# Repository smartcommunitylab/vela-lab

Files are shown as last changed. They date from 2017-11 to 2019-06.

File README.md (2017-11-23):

Smart City Vela Lab
========================

This repository contains the code for the embedded network devices used in the Smart City Lab located in Vela (Trento, Italy).
The network components are:
- BLE Beacons: Eddystone or CLIMB (https://github.com/smartcommunitylab/sco.climb.driverapp) proprietary beacons
- BLE Scanner: Nordic nRF52 DK (nRF52832 SoC)
- Mesh Node: Texas Instruments cc2650 launchpad
- Mesh Sink: Texas Instruments cc2650 launchpad
- Gateway: Raspberry PI

The BLE Scanner and the Mesh Node are packed into the same case and together they are called Mobile Stack. The communication between the two boards happen through the UART interface. The same apply for the Mesh Sink and the Gateway, in this case the communication take place over an emulated serial port over USB.

The purpose of this network is to collect 'contacts' of BLE Beacons and push them, through the mesh network, to a cloud infrastructure (database).

For this purpose, the BLE Scanner scans for neighboring devices. When requested, the information regarding contacts (for instance the list of IDs with their RSSI) are passed to the Mesh Node, which injects this data into the mesh network. When the data reach the Mesh Sink it forward it to the Gateway that push the data to the cloud.

The deployment is at very early stage, than the code may have bugs and the compilation process may not be straigh forward, nevertheless we try to describe the steps for setting up the environment in the README-BUILDING.md file in this directory.

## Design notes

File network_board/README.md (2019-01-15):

Mesh devices
========================

This folder contains the code specifically developed for the Mesh Node and for the Mesh Sink. Note that external sources/libraries may be required. Every folder contains all the code required to compile a fully working program. 

The folder basic_i2c_init includes the files for setting up i2c communication to communicate with the fuel gauge on the PCB.

The folder basic_sender_test includes the files used for the network/application layer of the nodes and sink.

The folder basic_sink includes files used for the sink, but these are outdated. The current version is in basic_sender_test.

The folder basic_uart_init contains the files used for the UART communication between the node and the Nordic.

The folder integrate_sender_uart contains the code that will be uploaded to the nodes during deployment. When using the buildscript the following files are copied into this folder:
-basic_uart_init/vela_uart.c 
-basic_uart_init/vela_uart.h 
-basic_sender_test/vela_sender.c 
-basic_sender_test/vela_sender.h 
-basic_sender_test/sink_receiver.c
-basic_sender_test/sink_receiver.h

Warning: Editing these files should be done in their original folder. If you change these files in integrate_sender_uart all progress will be lost when the build script is called. 

The following problems have been encountered in the past:
-RPL_DEFAULT_ROUTE_INFINITE_LIFETIME: setting this to 0 can cause the nodes to lose connection to the sink frequently.
-NETSTACK_CONF_RDC_CHANNEL_CHECK_RATE: setting this to 1 can cause the nodes to reboot periodically (cause unknown).
-Seemingly random reboots that were fixed by changing all variables to static when possible.

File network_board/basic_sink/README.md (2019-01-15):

Mesh Sink: basic
========================

Warning: this code may be outdated compared to the sink from basic_sender_test and integrate_sender_uart.
This code contains an example code of the program running on the Mesh Sink (TI cc2650). 
This example code prints any received messages.

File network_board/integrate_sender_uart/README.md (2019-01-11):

Integrate sender uart
========================

This code merges the two projects: basic_uart_init and basic_sender_test to make the firmware complete and able to use both the uart and the wireless mesh network.
The whole project contains just two c files: vela_node.c and vela_sink.c. The other needed files are copied from:
-basic_uart_init/vela_uart.c 
-basic_uart_init/vela_uart.h 
-basic_sender_test/vela_sender.c 
-basic_sender_test/vela_sender.h 
-basic_sender_test/sink_receiver.c
-basic_sender_test/sink_receiver.h
To do so, just run the copyForBuild.sh script before building.

Warning: Editing these files should be done in their original folder. If you change these files in integrate_sender_uart all progress will be lost when the build script is called.

Within this code are 4 processes.

-Vela_sender_process
This process is responsible for the sending of data through RPL and fragmenting it. The data includes BLE reports, pong messages, and battery data.

-Trickle_protocol_process
This process sends and handles incoming Trickle messages. Trickle messages are used to configure all the nodes in the network.

-Keep_alive_process
This process sends a periodic keep alive message. The interval of these keep alive messages can be changed by the gateway using Trickle messages.

-cc2650_uart_process
This process handles all UART communication between the CC2650 and the Nordic.

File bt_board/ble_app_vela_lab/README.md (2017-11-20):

BLE Scanner:ble app vela lab
========================

This code contains the program running on the Bluetooth Scanner device. Its behaviour is strictly correlated with the Mesh Node which is connected to the BLE Scanner through the UART interface.
At the boot the device is initialized but without any command by the Mesh Node the BLE Scanned doesn't do anything else, is up the the Mesh Node to start the Bluetooth and request the periodic Bluetooth contacts report.
This code is the actual code that is supposed to run on the BLE Scanner of the Vela Lab.
This code requires nRF5 SDK (v14.0.0) installed and linked (see the README-BUILDING.md at the repository root).

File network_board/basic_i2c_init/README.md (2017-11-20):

Mesh Node: test uart
========================

This code contains an example code of the program running on the Mesh Node (TI cc2650). 
This example do not use any kind of wireless interface.
The aim of this code is to show how to use the UART for communicating with the BLE Scanner. To this purpose the TI send forces an hard reset on the BLE Scanner, waits for the uart_ready packet, and then it start sending initialization packets (set BLE scan parameters, set BLE scan ON, request periodic report).
At this point the reports are automatically sent by the BLE Scanner to the Mesh Node.
As the full report is received it calls report_ready(uint8_t *p_buff, uint16_t size) where 'p_buff' points to the report and 'size' is its size. Note that the data stored in the buffer does not include the TYPE field, it is the raw list of contacts. 
For now the structure of the contacts isn't really fixed, to know the exact format look into: /bt_board/ble_app_vela_lab/main.c : add_node_to_report_payload(...)

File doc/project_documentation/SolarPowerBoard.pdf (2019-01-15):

# Solar power board

## Contents

## General description

The design of the power-board used to power nodes with solar energy is explained in this document. The design exists out of 5 stages: solar power input, USB power input, energy storage, a fuel gauge, and a DC/DC regulator to provide suitable power to the node. For clarification, a simplified version of the board is provided below.

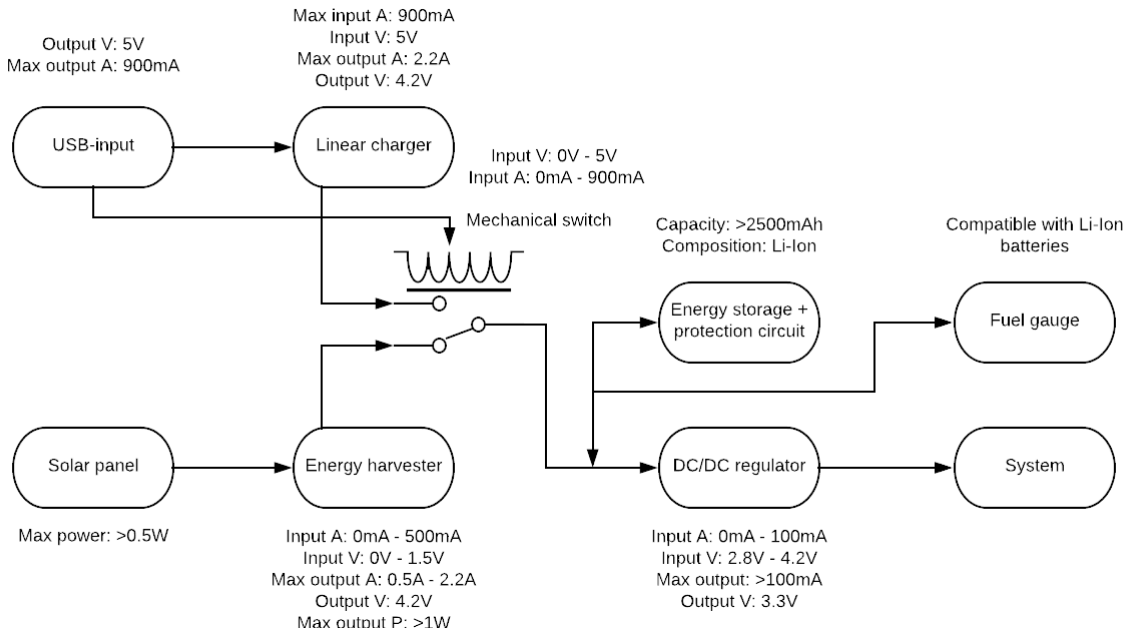
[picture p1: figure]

The board receives power from USB-input or from the solar panel. Once the node is deployed outside USB input won’t be utilized. The USB-input power is used when the node is being charged indoors. Input power goes through an IC (energy harvester or linear charger) to optimize/regulate the power for the rest of the circuit. The power will be used to power the system and to charge the battery. The battery will be used to power the system when there is no other power source available. The fuel gauge measures the state of the battery and can predict how long the battery can last. Before any source is used to power the system (including the battery), it passes the DC/DC regulator. This transforms the input voltage to an output voltage that is suitable for the system that will be powered.

The board has 2 charging options, with a USB connection or using a solar panel. USB charging will happen when the node is plugged into a laptop or pc. This won’t happen outside, so the solar panel will not be useful in this situation. When there is a high voltage on the USB-input, the relay will close the connection between the linear charger and the energy storage and open the connection between the solar panel and the energy storage. When the node is plugged out of the laptop or pc the connection between the energy storage and the linear charger opens again, and the connection between the energy storage and the solar power closes again.

The linear charger connected to the USB-input optimizes the charging of the battery. An FTDI chip is connected to the USB-input that functions as a USB to UART interface. The energy harvester connected to the solar panel maximizes the extracted power from the solar panel and regulates the output voltage. The energy storage has a protection circuit that disconnects the battery for charging or discharging in case of a detected fault.

The selected components are:

-USB-input FTDI chip: FT230XQ-R

-Linear charger: MCP73831T-2ACI/OT

- Solar panel: 1W Solar Panel 80X100 or Sparkfun 2W solar panel

-Energy harvester: SPV1040

-Protection circuit: BQ29700

-Energy storage: JA-18650 Li-Ion battery pack (S1P3)

-Fuel gauge: MAX17260DSET

-DC/DC regulator: TPS63031DSK

## Solar panel

Power consumption
The decision of what solar panel to use depends on the consumed power. In order to choose a suitable solar panel, the total power consumption and the efficiency must be calculated. Based on these 2 factors the size of the solar panel can be chosen.

Psolar panel * ηsystem > Pconsumed

Harvested energy
The amount of energy that will be harvested by a solar panel is dependent on 3 factors: solar irradiance, panel size, and efficiency.
This site shows how much solar irradiance lands on a city http://solarelectricityhandbook.com/solar-irradiance.html. (http://solarelectricityhandbook.com/solar-irradiance.html)
This can be used as an estimation of the available energy, keep in mind however that the mountains can obstruct sun which means less energy will be available than stated. Multiply the solar irradiance by the panel size (m2) and the panels efficiency and you have a very rough estimation of the amount of energy that will be harvested. The actual amount will be lower.

Output current
In order to ensure maximum efficiency, make sure the output current of the solar panel is not greater than the maximum charging current of the battery plus the power consumption from the boards. If that is not the case, not all the harvested energy can be used.

## Energy harvester

Function
The energy harvester’s (SPV1040) task is to extract power from the solar panel. This component is needed because the solar panel’s output is unstable. Of course, the output power depends on the amount of sun on the panel, and since this varies a lot throughout the day the output will change a lot. The energy harvester takes the irregular input from the solar panel and stabilizes it, so the output of the energy harvester can be used to charge a battery. Another important feature of this component is MPPT. Not every energy harvester has this feature, but it is an important one. MPPT ensures that the highest possible amount of power is harvested from the solar panel, by dynamically finding the voltage point at which the power harvested is the greatest. The input voltage range of the SPV1040 (0 – 5.5V) may seem too low for the solar panel’s output voltages (up to 6V), but after consulting with someone who has more experience in this field, it has been decided this should not be a problem.

Maximum ratings:
Input voltage: 5.5V
Input current: 1.8A
Output voltage: 5.2V

Configuring the output
Below is the schematic of the SPV1040 including passive components:

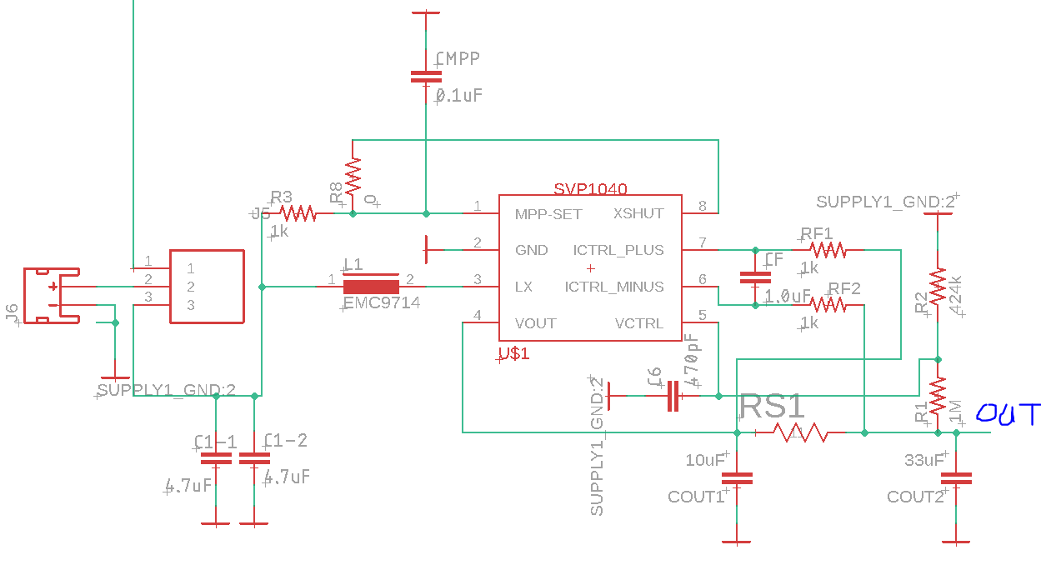
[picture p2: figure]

Figure 1 SPV1040 schematic. (jumper pin 1 is an optional bypass)

The output voltage can be set using R1 and R2 using the following formula: R1
R2

=

Voutmax
1.25
Where R1 is 1Mohm.

The maximum output current can be limited with RS1 using the following formula:

RS1 =

50mV
Ioutmax

For more details refer to application note ST AN3319.

Rejected alternatives
Several different energy harvesters are available, but the SPV1040 was the best fit. Most energy harvesters were deemed not suitable based on voltage input range or maximum output/input current.
The LTC4010 was deemed not suitable because of the high quiescent current.
The BQ24210 seemed like a good option as well, but it did not have MPPT.
The SVP1050 had a maximum charging current of 70mA, which would mean a lot of energy would be wasted.
BQ25504 had an input voltage range that only allowed a maximum of 3V input, which was way too low.

## FT230XQ-R

Function
This chip is used to handle the communication that happens over the USB connection when the board is plugged into a laptop or something similar. It converts the USB signals to UART so the signals can be understood by the boards. This chip is also used to open a switch once the USB input enters sleep mode, so the charging will be terminated when there is barely any current entering the circuit from the USB connection.

## MCP738312

Function
The MCP is a linear charger used to charge the battery with the power coming in from the USB port.

Output current
The output current is set with the resistor RProg at the PROG pin. The current value of 2k ohm sets the output current at the maximum current possible, 500mA.

## Protection circuit

Function
This circuit has its own battery protection circuit to prevent several faults, such as overcharging, over discharging, overcurrent charging, overcurrent discharging. This protection circuit is suitable with any 3.7V Li-Ion battery. The protection circuit has 2 MOSFET’s connected between the negative battery terminal and the ground. As soon as an error is detected one MOSFET will be set open, blocking either charging or discharging of the battery depending on the error. This way the battery can still be discharged when the charging is terminated, and the battery can still be charged when it’s discharged all the way. This would not be possible using only one MOSFET and simply disconnecting the battery whenever a fault is detected. The protection IC uses voltage sensing and current sensing to detect faults.

Battery type
This protection circuit only works with Li-Ion battery packs that doesn’t have any cells in series.

Overcurrent charging and overcurrent discharging
In the current circuit overcurrent charging and overcurrent discharging are not correctly configured, they are too high. Since the battery that is currently used has a fast charging rating of 1C (2.2A), limiting the charging current is not needed. The SPV1040 regulates the output current and will shut off as soon as the input current rises above 1.8A. Also, research shows overcurrent charging is not dangerous (Tazdin Amietszajew, 2018). The discharge rate of the battery is rated at 0.5C (1.1A). But the absolute maximum rating of the DC/DC converter is 1.1A (which will practically be even less), so there is also no risk of discharging the battery with a current that is too high. If this circuit is changed however, the overcurrent values might have to be configured correctly.

Rejected alternative
The BQ2980 was also considered as protection circuit, however the standard protection values of the BQ2980 weren’t as good as the BQ2870’s values.

## Energy storage

Constraints
The energy storage can be varied without any changes in the circuit, if the following characteristics are the same:
- Battery chemistry: Li-Ion
- Charging voltage: 4.2V
- Battery voltage when fully charged: 4.2V
- Battery voltage when fully discharged: 2.8V

These values are fixed by the protection circuit, so if energy storage with other characteristics are required either select another version of the BQ270x or choose another protection IC.

The maximum charging and discharging current depend on the SPV1040, the protection circuit, and the DC/DC regulator. Refer to the sections of these 2 components to find these currents.

## Fuel gauge

Function
The fuel gauge measures the State of Charge (SoC) of the battery. It implements the ModelGauge m5 algorithm to measure the SoC using coulomb counting, voltage sensing, and an internal temperature sensor. What makes this part very suitable for this project are the low operating current (5uA) and the option to use high-side sensing. Most fuel gauges use low side sensing, but this is not possible for our application. The protection circuit already uses low side current sensing, and having 2 current sense resistors on the same net will cause inaccurate measurements. The fuel gauge contains a lot of data concerning the battery’s state. This data can all be accessed by connected microcontrollers using I²C. The fuel gauge also contains an alert pin to alarm a connected microcontroller in case of a problem (1% SoC left, for example). Important: when connecting the fuel gauge’s sense resistor it is important to do so with a kelvin connection for good accuracy.

Battery type
Li-Ion and LiFePO4 batteries can be used with this fuel gauge. Battery packs with cells that are connected in series will not work with this fuel gauge.

Rejected alternatives
The following fuel gauges were compared to each other: FFG1040UC003X, MAX17043, GG25L, STC3115, MAX1720. The STC3115 was found to be the most efficient. When the protection circuit came into the circuit none of these were suitable anymore, because none of these circuits can use high-side sensing. Also, the energy consumption of all these components is higher than that of the MAX17260.

## DC/DC regulator

Function
The DC/DC regulator transforms its input to a suitable power for the 2 boards. It’s a buck/boost converter, meaning it can output a voltage that is lower or higher than its input voltage. It is optimized for low power application and has a high efficiency (~90%). The output voltage is fixed at 3.3V which is exactly what the boards need.

Maximum ratings:
Input voltage: 1.8V – 5.5V
Output voltage: Fixed at 3.3V
Average current limit: 1A

Rejected alternatives
The previously selected DC/DC regulator TPS62737 was only a buck converter, meaning it could only step-down voltages. This causes problems when the input voltage of the regulator drops below 3.3V. This will happen when the solar panel doesn’t have much sunlight available, or when the battery is discharged a lot. Also, the efficiency of this regulator is not great at the low currents with which the boards have to be supplied.

## Optional connections

There are a few jumpers and DNM resistors throughout the schematic. Their use is explained below:

Jumper at solar panel connection

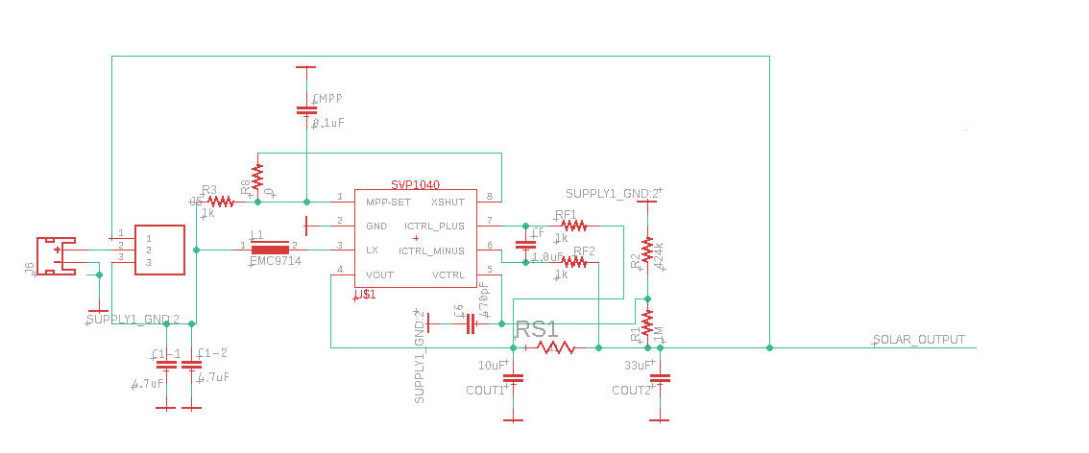
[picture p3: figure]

The jumper at the solar panel connection can be used to bypass the energy harvester. This can be done in case energy harvester is not working, but the solar panel still needs to be tested.

R24

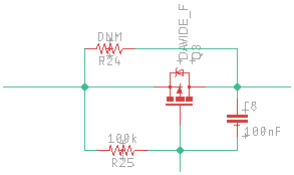
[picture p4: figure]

R24 can be mounted to bypass the switch used to cut off the charging power when the USB enters sleep mode.

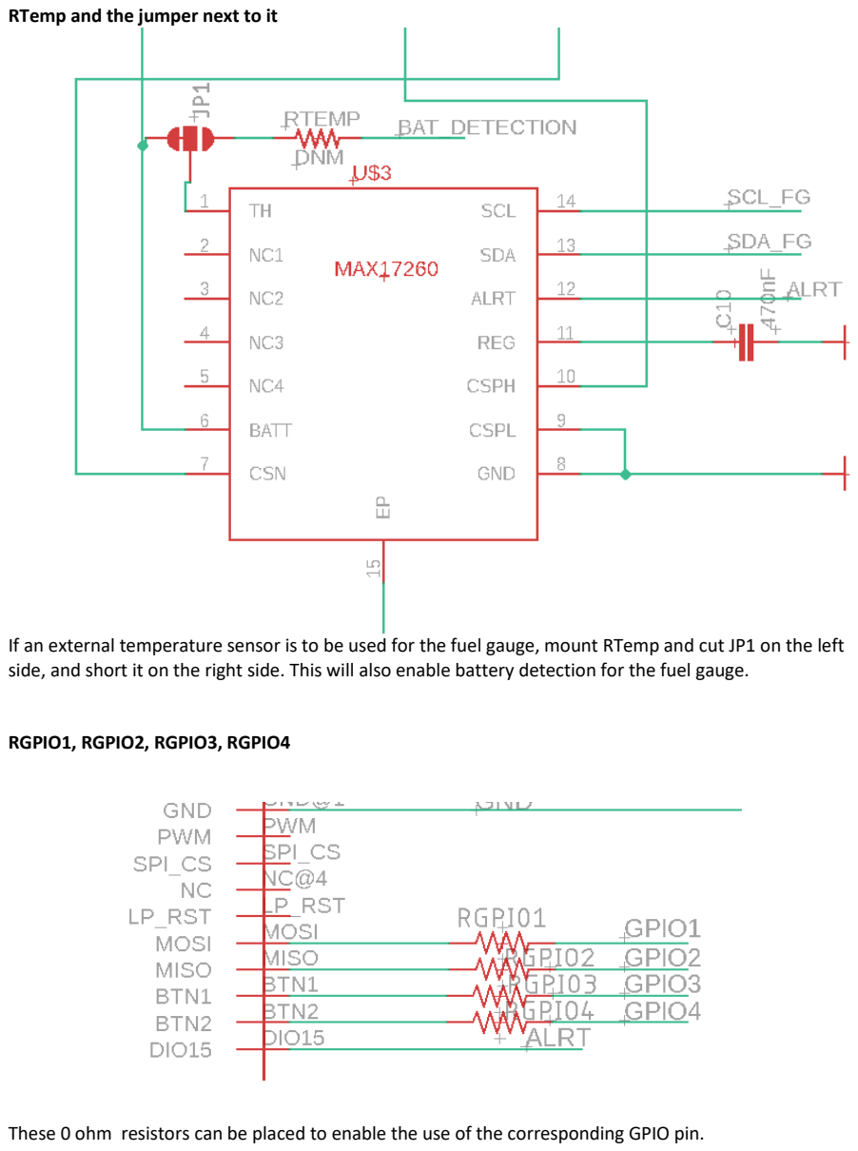
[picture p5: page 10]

RTemp and the jumper next to it

If an external temperature sensor is to be used for the fuel gauge, mount RTemp and cut JP1 on the left side, and short it on the right side. This will also enable battery detection for the fuel gauge.

RGPIO1, RGPIO2, RGPIO3, RGPIO4

These 0 ohm resistors can be placed to enable the use of the corresponding GPIO pin.

SDA jumper

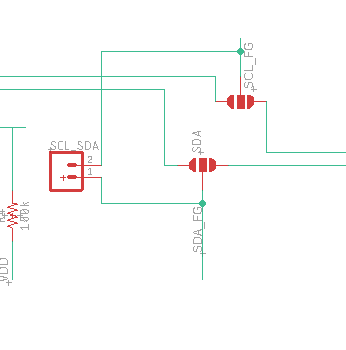
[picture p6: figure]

The SDA jumper should be shorted at least one side to allow the board at the shorted side to communicate with the fuel gauge. If both sides of the jumper are open the fuel gauge is useless.

## Bibliografia

Tazdin Amietszajew, E. M. (2018). Understanding the limits of rapid charging using instrumented commercial 18650 high-energy Li-Ion cells. Coventry: Elsevier.

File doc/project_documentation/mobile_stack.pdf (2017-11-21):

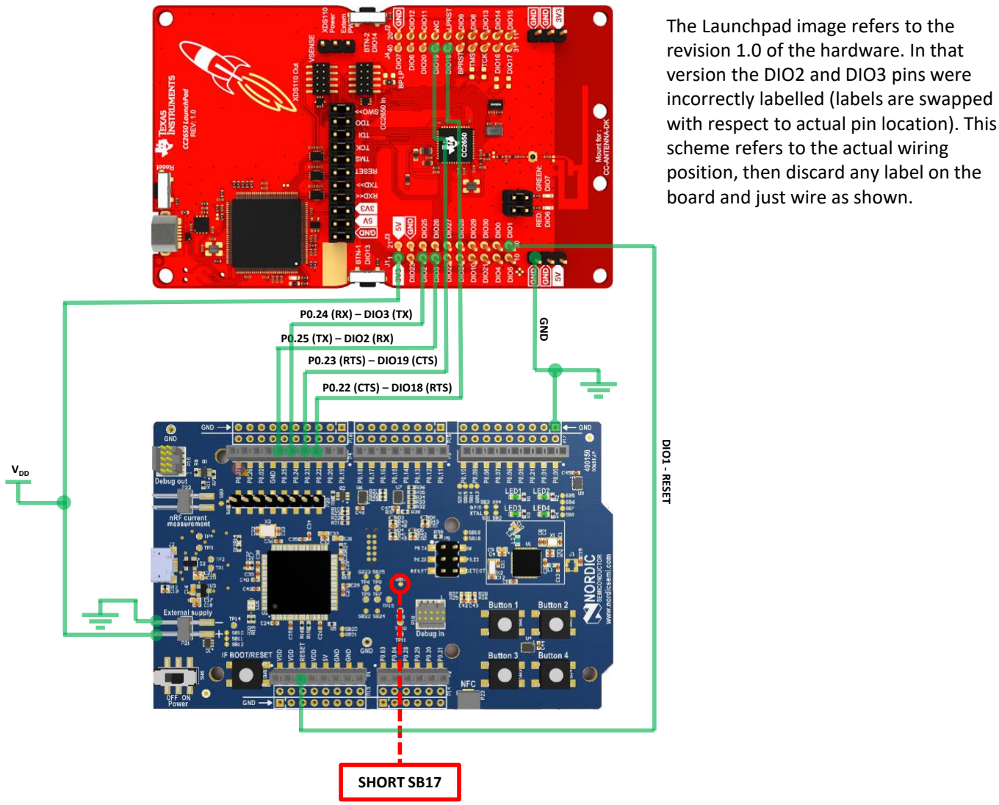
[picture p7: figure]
SHORT SB17; DIO1 - RESET; P0.22 (CTS) – DIO18 (RTS); P0.23 (RTS) – DIO19 (CTS); P0.25 (TX) – DIO2 (RX); P0.24 (RX) – DIO3 (TX); GND; VDD; The Launchpad image refers to the revision 1.0 of the hardware. In that version the DIO2 and DIO3 pins were incorrectly labelled (labels are swapped; scheme refers to the actual wiring position, then discard any label on the board and just wire as shown.

with respect to actual pin location). This

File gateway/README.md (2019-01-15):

Gateway
========================

The Gateway is implemented in python 3 on a Raspberry Pi 3 running Raspiban (ver. June 2017, Kernal 4.9).

Its main functions are:
- read incoming data from the Mesh Sink via serial port (virtual serial port on USB, /dev/ttyACM0)
- defragment (optionally) and decode data from the sink and recode it to the desired internal structures and into a json object
- send the data to the smartcommunity back-end server and log the data
- use the Mesh Sink to send configuration messages into the mesh network based on user input
- log events and data for debugging and testing purposes

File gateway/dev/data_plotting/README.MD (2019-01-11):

This folder contains 3 scripts which are usefull for debugging or analyzing the log files of the gateway.

The first file, applog_plotting.py plots all the battery data and dropped packets based on the log file app.log. 
This file is generated by the script main.py which will run on the gateway during deployment. 
At the moment this script can only plot graphs based on the data of one node. 
Lines 14 and 22 decide from what node's data the graphs should be plotted.

contact_plotter.py plots the RSSI of Bluetooth beacons detections measured by the nodes. 
The data is gathered from the file contact.log which is also generated by the main.py script.
By default this script only works when there is data of 4 different nodes in contact.log, but this can easily be adjusted by:
-Changing the subplotvalues in lines 105 and 108
-Commenting or adding lines to lines 50-53

node_data_logging.py is a script that reads the serial data from a device and logs it to a file with a timestamp.
The file is called [timestamp]-data.log and a new one is generated every time the script is ran.

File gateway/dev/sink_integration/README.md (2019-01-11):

The script main.py is the script that will run on the gateway during deployment.

This script has the following functions:
-Receiving packets from the sink through a serial port and interpreting and (optionally) defragmenting the messages.
-Control the nodes in the network based on user input.
-Log all events for debugging purposes
-Log all received contacts from the nodes.
-Log all the received and sent packets (raw).

Bugs:
-The packet delivery stats that are monitored throughout the script and displayed when the script is closed are wrong. The latest packet of a node is not correctly saved in the function check_for_packetdrop().

To be added:
-Uploading all contacts to a server.

Defragmentation
When the first part of a fragment is received it is kept as a "sequence". A sequence is a list that will contain all the fragments that belong to eachother. When the last fragment of a sequence is received the data of all the fragments gets logged and then the sequence gets deleted so that a new one can be started. Sequences are based on the ID of the sender of the fragment. A sequence is ended when a fragment with the packet type network_last_sequence is received.

User input
The user input is a number that gets entered into the terminal.
The following options are available:
-Request ping
-Enable bluetooth
-Disable bluetooth
-Enable Bluetooth with default settings
-Enable Bluetooth with custom parameters
-Enable the sending of battery info
-Disable the sending of battery info
-Reset all Nordics
-Set keep alive interval in seconds (9 - 254 seconds)

Logfiles
[timestamp]-data.log contains all the logged raw packets.
[timestamp]-contact.log contains all the logged contacts.
[timestamp]-app.log contains all the logged events.

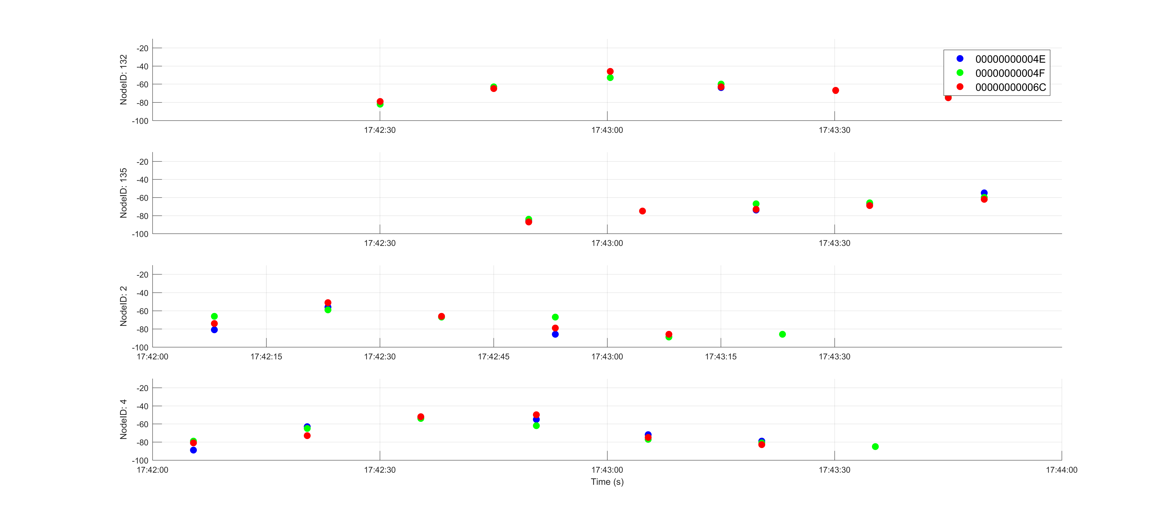
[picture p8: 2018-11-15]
back_end/matlab/45_node.png

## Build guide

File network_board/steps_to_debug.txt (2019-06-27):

24/01/2019 
The nodes still reboot. Once or twice every day when the BT is used
It doesn't look to be directly caused by the uart since the reboots not always happen at the same time. Some times they are very close to the uart communication, some other times are 5 seconds before, sometimes just after a transaction (however I never seen a reboot DURING a uart communication)
Today I'm running a test without the bluetooth (the board is there and the uart is initialized, but the bt scanning isn't enabled). If a reboot will happen it confirms that the cause is not the uart. -> I had one reboot during a weekend even with no uart communication
I have some suspects that the problem is due to some low level race condition
Today I enabled some logs at low level in contiki (contikimac.c, ctimer.c, rtimer.c, ieee-mode.c, rf-core.c, contikimac.c, contikimac_framer.c, nullrdc.c). I try with low level debug and with uart.

30/01/2019
from 24/01 I tried changing the channel check rate, enabling logging at mac layer. Reboots are still there (typically 1 every day, sometimes up to 4) and they happen anywhere (during uart communication, far from uart communication, inbetween uart communications). With the BT DISABLED there are less, but some are still there. Today I run a test with: mac logging enabled, BT off, battery report every 15s, keep alive every 12s, NETSTACK_CONF_RDC_CHANNEL_CHECK_RATE 8

06/03/2019
I tried using 868MHz boards (cc1350) and this one uses by default the PROP_MODE in place of IEEE_MODE that is used in the cc2650. These boards remained outdoor for a couple of weeks. Two of them shown problems: NODEID=5 was not working at all (the red LED was ON and the BT board was in IDLE state), I had to reset it to make it working again. NODEID=3 responded to network commands, however the BT board did not work, even after BT reset command (even ping did not work, the nordic does not respond to ping with pong). After hard reset of the whole node the BT started working again.
Today I run a test with 868MHz radio and PROP_MODE and I remove nodeID=1 since it is the same of the sink...

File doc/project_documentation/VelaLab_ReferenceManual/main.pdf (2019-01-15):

# VelaLab reference Manual

### January 15, 2019

## 1 System Architecture

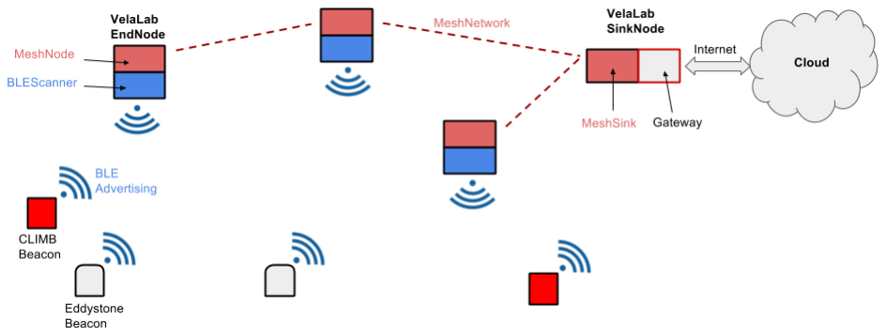
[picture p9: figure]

Figure 1:

### 1.1 Namings and definitions

BLE Beacon
Any beacon device that can be detected from the system. Now it can be of two types: CLIMB Beacon and Eddystone Beacon.

VelaLab EndNode
One of the nodes forming the BLE+mesh network. It is formed by a BLE Scanner and a Mesh Node, which communicate via a serial connection (UART).

1

BLE Scanner
BLE part of an EndNode, based on the Nordinc nRFxx and implemented on the nRFxxx development board.

Mesh Node
Mesh/Contiki part of an EndNode, based on the TI CCxxxxx and implemented on the Lauchpad xxx dev board.

VelaLab SinkNode
The sink/gateway node of the network. It combines the Mesh Sink and the Gateway, which are connected using the serial to USB feature on the Mesh Sink. It does not have the BLE Scanner (only mesh and gateway)

Mesh Sink
The sink node for the mesh/contiki network. Its hardware is equivalent to a Mesh Node, but it has a different firmware.

Gateway
The gateway between the network and the internet/cloud. It is implemented using a Raspberry PI 3 (RPI). The Mesh Sink is connected through a USB port and it connects to the internet through Ethernet or WiFi.

Contact Data Structure
Contact Data is the data structure containing the information about the contact of one BLE Beacon. A Report is an array of Contact Data containing all the data received during the last epoch. All the reported parameters refer to the last epoch.
Field | Type | Size (Byte)
NodeID | uint | 6
lastRSSI | int | 1
maxRSSI | int | 1
pktCounter | u8 | 1

Back-End Data Structure (as in CLIMB)
Data structure containing the information to be sent from the gateway to the server, encoded as a json object. Each call send an array of such objects.

2

Field | Type
wsnNodeId | string
eventType | int
timestamp | int
payload | object

Payload may contain:

Field | Type
passengerId | string
latitude | float
longitude | float
accuracy | float

## 2 Beacons

Types:

- CLIMB (custom)
- Eddystone

## 3 VelaLab End-Node

Components:

- BLE Scanner
- Mesh Node

### 3.1 Hardware interconnection

fig...
The Launchpad image refers to the revision 1.0 of the hardware. In that version the DIO2 and DIO3 pins were incorrectly labelled (labels are swapped with respect to actual pin location). This scheme refers to the actual wiring position, then discard any label on the board and just wire as shown.

3

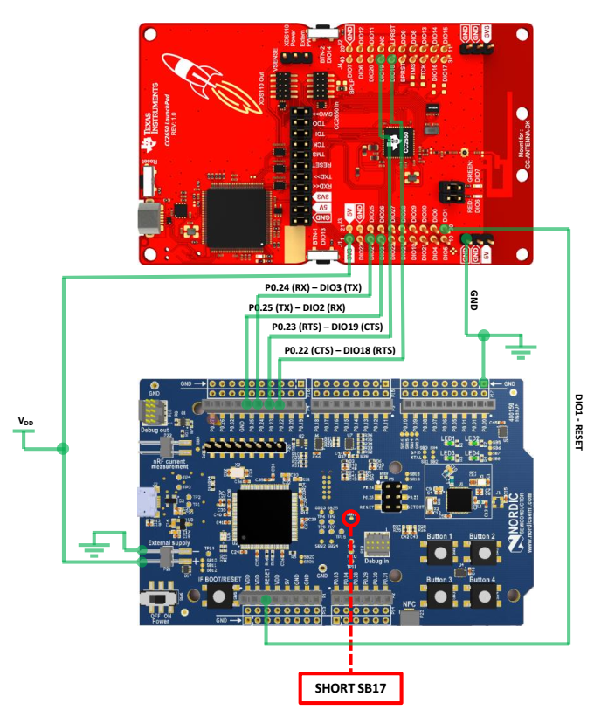
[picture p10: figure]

Figure 2:

### 3.2 Communication protocol

UART communication protocol between BLE Scanner and Mesh Node

## 4 VelaLab Sink-Node

Components:

- Mesh Sink
- Gateway

4

### 4.1 Hardware interconnection

Launchpad usb output to RPI’s USB

### 4.2 Communication protocol

UART communication protocol between Mesh Sink and Gateway

## 5 Mesh network

### 5.1 Mesh Nodes to Sink-Node

The mesh network consists of atleast one Mesh Node and a single Mesh Sink. The destination of all the messages from the Mesh Nodes is the Mesh Sink. The Mesh Nodes will send 3 types of messages to the Mesh Sink: reports, keep alive messages, and battery data. Reports may get fragmented into fragments containing a maximum of 6 reports. Fragments only contain complete detections so that when a fragment gets lost the data from the other fragments can still be used. The Mesh Sink will send all its data to the gateway for decoding and defragmentation. All the Mesh Sink does is receive data and send it to the gateway without any checks or decoding etc.

### 5.2 Gateway to Mesh Nodes

For configuring the Mesh Nodes in the network the gateway can send messages into the mesh network through the Mesh Sink. The following parameters can be configured: Enabling/disabling Bluetooth, Bluetooth duty cycle, keep alive messages interval, and battery info messages interval. The gateway sends a message to the Mesh Sink and the Mesh Sink will propegate a duplicate of this message through the mesh network using the Trickle protocol. This happens based on user input in the python script running on the gateway.

5

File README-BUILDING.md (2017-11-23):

Building the Smart City Vela Lab
========================

This guide is for linux machines (tested with Ubuntu 16.04 LTS).

Building the code for the components of the Vela Lab requires some external modules and some external tools not included in this repository.
Before building install the following prerequisite software :
* Install the GCC ARM Embedded toolchain (tested with version 4.9.3-20150529 but is should work also with newer versions)
* Install Python (tested with version 2.7.12 but it should work for version newer than 2.6)
* Download and decompress Nordic nRF5 SDK (https://developer.nordicsemi.com/) (this must be the version 14.0.0, probably it works for version 14.x)
* Download the Contiki sources (https://github.com/contiki-os/contiki)

Once done clone the repository with
git clone https://github.com/smartcommunitylab/vela-lab.git

Building the BLE Scanner firmware
========================
cd /bt_board/ble_app_vela_lab/pca10040/s132/armgcc

Open build_script.sh with a file editor and substitute {absolute_path_to_nordic_sdk} with the absolute path of the Nordic nRF5 SDK root.

Fix permissions:

chmod +x build_script.sh

Run the build_script.sh with

./build_script.sh

Building the Mesh Node Example
========================
cd /network_board/basic_uart_init

Open build_script.sh with a file editor and substitute {absolute_path_to_contiki} with the absolute path of the Contiki sources root

Fix permissions:

chmod +x build_script.sh

Run the build_script.sh with

./build_script.sh

[Next section TODO]
For flashing the devices these further tools are required:
* NRF tools 
* TI xds probe drivers (included in Code Composer)

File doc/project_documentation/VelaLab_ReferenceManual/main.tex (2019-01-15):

\documentclass[12pt]{article}

\usepackage{cite}
\usepackage{graphicx}
\usepackage{subfigure}
\usepackage{epsfig}
\usepackage{epstopdf}
\usepackage{subfigure}
\usepackage{calc}
\usepackage{amssymb}
\usepackage{amstext}
\usepackage[fleqn]{amsmath}

\title{VelaLab reference Manual}

%\author{
%        Vitaly Surazhsky \\
%                Department of Computer Science\\
%        Technion---Israel Institute of Technology\\
%        Technion City, Haifa 32000, \underline{Israel}
%            \and
%        Yossi Gil\\
%        Department of Computer Science\\
%        Technion---Israel Institute of Technology\\
%        Technion City, Haifa 32000, \underline{Israel}
%}

\date{\today}

\begin{document}
\maketitle

%\begin{abstract}
%This is the paper's abstract \ldots
%\end{abstract}

\section{System Architecture}

\begin{figure}[h]
	\centering
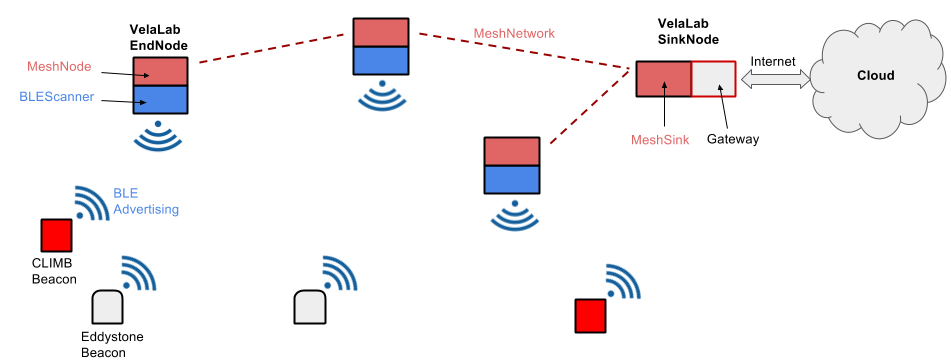
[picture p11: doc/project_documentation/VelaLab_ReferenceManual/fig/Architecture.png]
	
	\caption{}
	\label{fig:system}
\end{figure}

\subsection{Namings and definitions}

%\subsubsection{BLE\_Beacon}
\textbf{BLE\_Beacon}

Any beacon device that can be detected from the system. Now it can be of two types: \textit{CLIMB\_Beacon} and  \textit{Eddystone\_Beacon}.
\\

\noindent \textbf{VelaLab\_EndNode}

One of the nodes forming the BLE+mesh network. It is formed by a \textit{BLE\_Scanner} and a \textit{Mesh\_Node}, which communicate via a serial connection (UART).

\noindent \textbf{BLE\_Scanner}

BLE part of an EndNode, based on the Nordinc nRFxx and implemented on the nRFxxx development board.
\\

\noindent \textbf{Mesh\_Node}

Mesh/Contiki part of an EndNode, based on the TI CCxxxxx and implemented on the Lauchpad xxx dev board.
\\

\noindent \textbf{VelaLab\_SinkNode}

The sink/gateway node of the network. It combines the Mesh\_Sink and the Gateway, which are connected using the serial to USB feature on the Mesh\_Sink. It does not have the BLE\_Scanner (only mesh and gateway)
\\

\noindent \textbf{Mesh\_Sink}

The sink node for the mesh/contiki network. Its hardware is equivalent to a Mesh\_Node, but it has a different firmware.
\\

\noindent \textbf{Gateway}

The gateway between the network and the internet/cloud. It is implemented using a Raspberry PI 3 (RPI). The Mesh\_Sink is connected through a USB port and it connects to the internet through Ethernet or WiFi.
\\

\noindent \textbf{Contact\_Data Structure}

\textit{Contact\_Data} is the data structure containing the information about the contact of one BLE Beacon. A \textit{Report} is an array of \textit{Contact\_Data} containing all the data received during the last epoch. All the reported parameters refer to the last epoch.
\\

\begin{tabular}{l|l|l}
Field 		& Type 		& Size (Byte)\\
\hline
\texttt{NodeID} 		& uint		& 6\\
\texttt{lastRSSI} 		& int			& 1\\
\texttt{maxRSSI} 		& int			& 1\\
\texttt{pktCounter} 	& u8			& 1\\
\end{tabular}
\\

\noindent \textbf{Back-End Data Structure (as in CLIMB)}

Data structure containing the information to be sent from the gateway to the server, encoded as a json object. Each call send an array of such objects.
\\

\begin{tabular}{l|l}
Field 			& Type\\
\hline
\texttt{wsnNodeId} 		& string	 \\
\texttt{eventType} 		& int		 \\
\texttt{timestamp} 		& int		 \\
\texttt{payload} 			& object	 \\
\end{tabular}
\\

Payload may contain:
\\

\begin{tabular}{l|l}
Field 			& Type 	\\
\hline
\texttt{passengerId} 		& string	 \\
\texttt{latitude} 			& float	 \\
\texttt{longitude} 		& float	 \\
\texttt{accuracy} 			& float	 \\
\end{tabular}
\\

%[{
%    "wsnNodeId" : "<id>",
%    "eventType" : 901,
%    "timestamp" : <timestamp>,
%    "payload" : {
%        "passengerId" : "a511a089-ab7a-446f-a8c2-4c208d4425c5",
%        "latitude" : 46.0678106,
%        "longitude" : 11.1515548,
%        "accuracy" : 18.5380001068115
%    }
%}]

\section{Beacons}

Types:
\begin{itemize}
\item{CLIMB (custom)}
\item{Eddystone}
\end{itemize}

\section{VelaLab End-Node}

Components:
\begin{itemize}
\item{BLE Scanner}
\item{Mesh Node}
\end{itemize}

\subsection{Hardware interconnection}

fig...

\begin{figure}[!h]
	\centering
	
	\caption{}
	\label{fig:system}
\end{figure}

The Launchpad image refers to the revision 1.0 of the hardware. In that version the DIO2 and DIO3 pins were incorrectly labelled (labels are swapped with respect to actual pin location). This scheme refers to the actual wiring position, then discard any label on the board and just wire as shown.

\subsection{Communication protocol}

UART communication protocol between BLE Scanner and Mesh Node

\section{VelaLab Sink-Node}

Components:
\begin{itemize}
\item{Mesh\_Sink}
\item{Gateway}
\end{itemize}

\subsection{Hardware interconnection}

Launchpad usb output to RPI's USB

\subsection{Communication protocol}

UART communication protocol between Mesh Sink and Gateway

\section{Mesh network}
\subsection{Mesh\_Nodes to Sink-Node}
The mesh network consists of atleast one Mesh\_Node and a single Mesh\_Sink.
The destination of all the messages from the Mesh\_Nodes is  the Mesh\_Sink.
The Mesh\_Nodes will send 3 types of messages to the Mesh\_Sink: reports, keep alive messages, and battery data.
Reports may get fragmented into fragments containing a maximum of 6 reports. 
Fragments only contain complete detections so that when a fragment gets lost the data from the other fragments can still be used.
The Mesh\_Sink will send all its data to the gateway for decoding and defragmentation. 
All the Mesh\_Sink does is receive data and send it to the gateway without any checks or decoding etc.

\subsection{Gateway to Mesh\_Nodes}
For configuring the Mesh\_Nodes in the network the gateway can send messages into the mesh network through the Mesh\_Sink.
The following parameters can be configured:  Enabling/disabling Bluetooth, Bluetooth duty cycle, keep alive messages interval, and battery info messages interval.
The gateway sends a message to the Mesh\_Sink and the Mesh\_Sink will propegate a duplicate of this message through the mesh network using  the Trickle protocol.
This happens based on user input in the python script running on the gateway.

%\bibliographystyle{abbrv}
%\bibliography{main}

\end{document}
This is never printed

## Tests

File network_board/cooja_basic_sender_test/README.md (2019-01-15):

Mesh Sink and Mesh Node: fake uart
========================

This folder contains the code that will run on the Mesh Sink and Mesh Node.
The UART interface in this version is fake and will generate fake data every 60 seconds.
This will only happen on the Mesh Node since the Mesh Sink has a different UART interface just for the gateway.
The generated data will be sent to the vela_sender_process in vela_sender.c and will get fragmented and sent through the mesh network.
Eventually the Mesh Sink will receive this data from the mesh network and it will sent this data to the gateway through UART.
Periodically keep alive messages and battery data will also get sent.
Depending on wether or not there is a valid fuel gauge connected and on the target of the project, fake or real battery data will get sent.

vela_sender.c, vela_sender.h, sink_receiver.c, and sink_receiver.h will also be used by the project integrate_sender_uart.

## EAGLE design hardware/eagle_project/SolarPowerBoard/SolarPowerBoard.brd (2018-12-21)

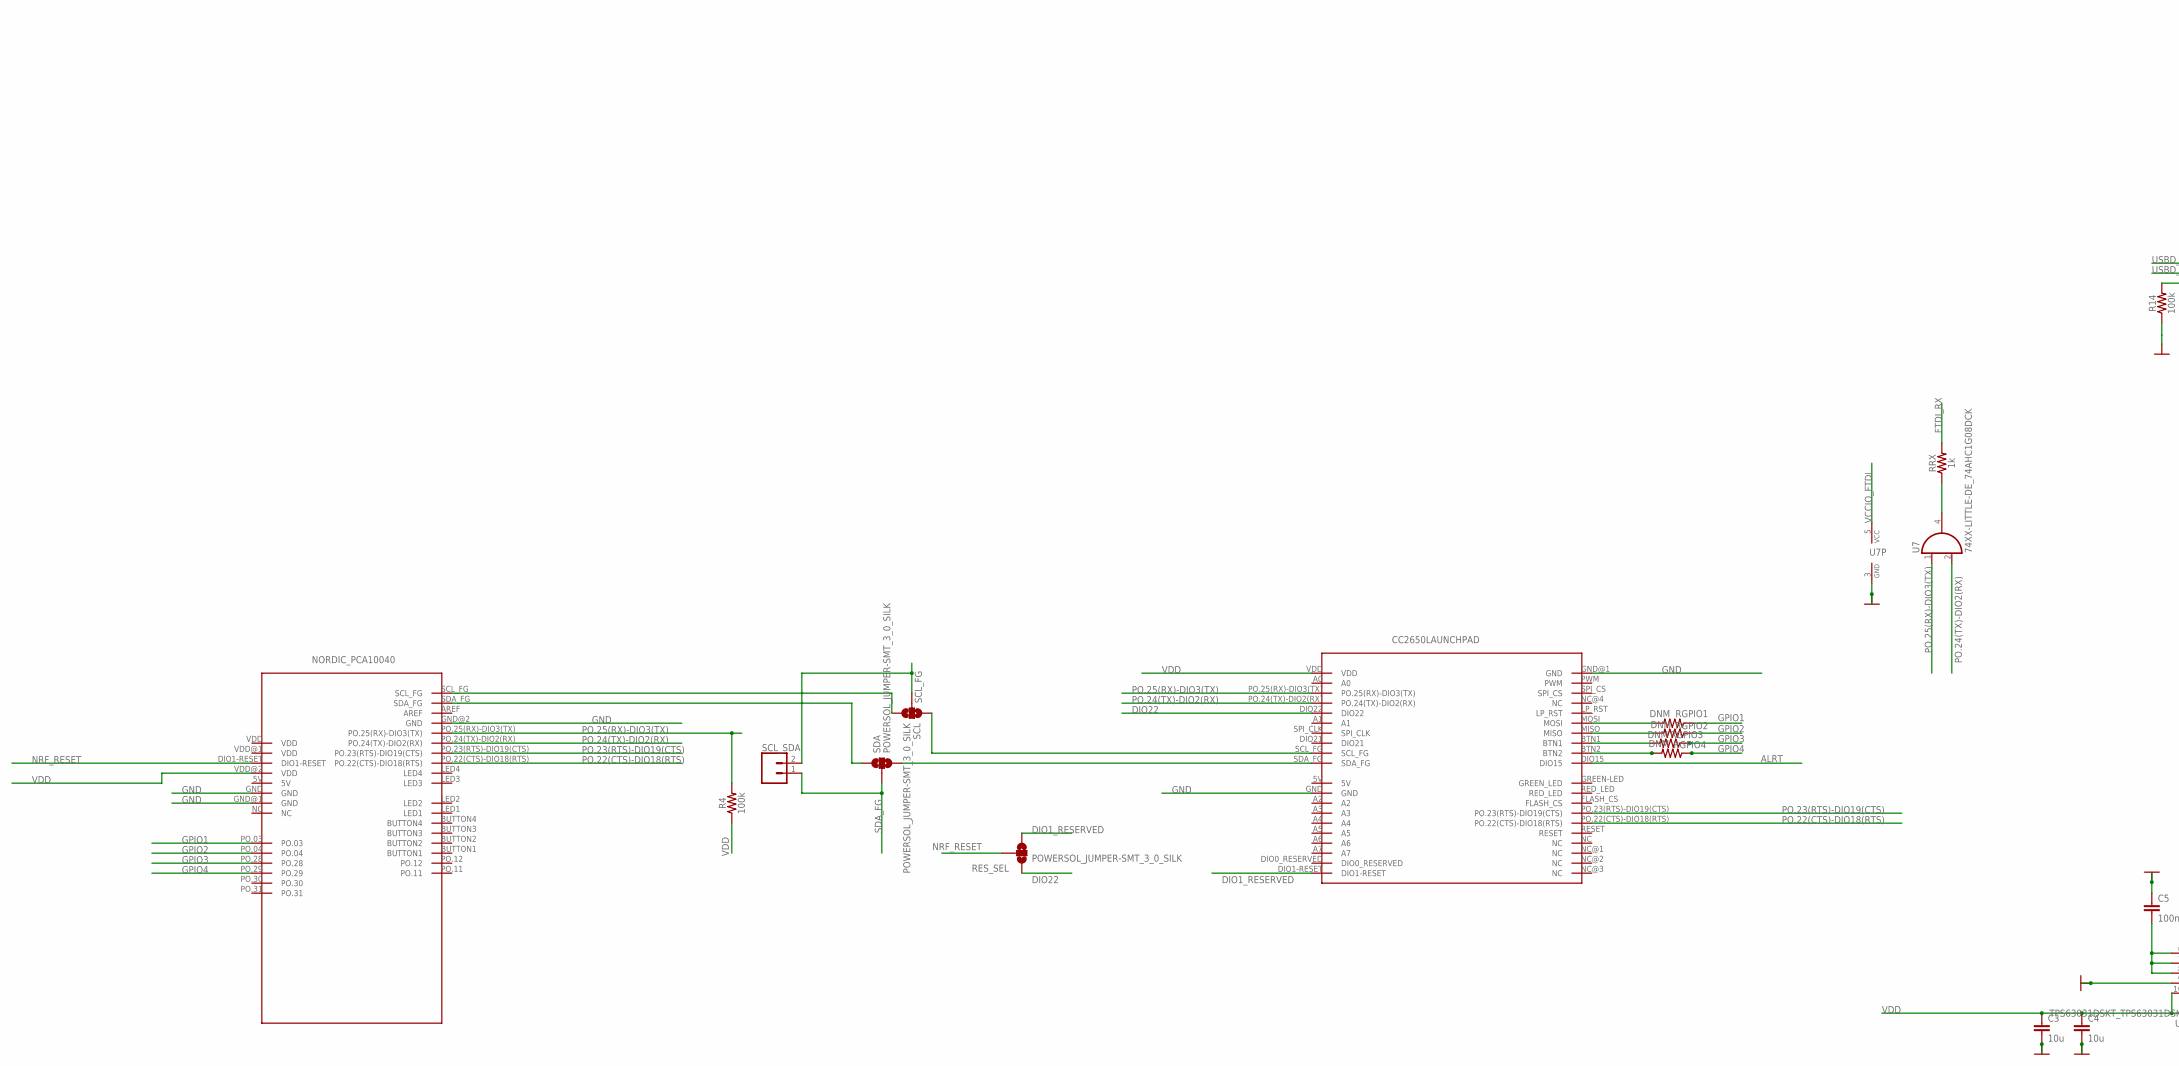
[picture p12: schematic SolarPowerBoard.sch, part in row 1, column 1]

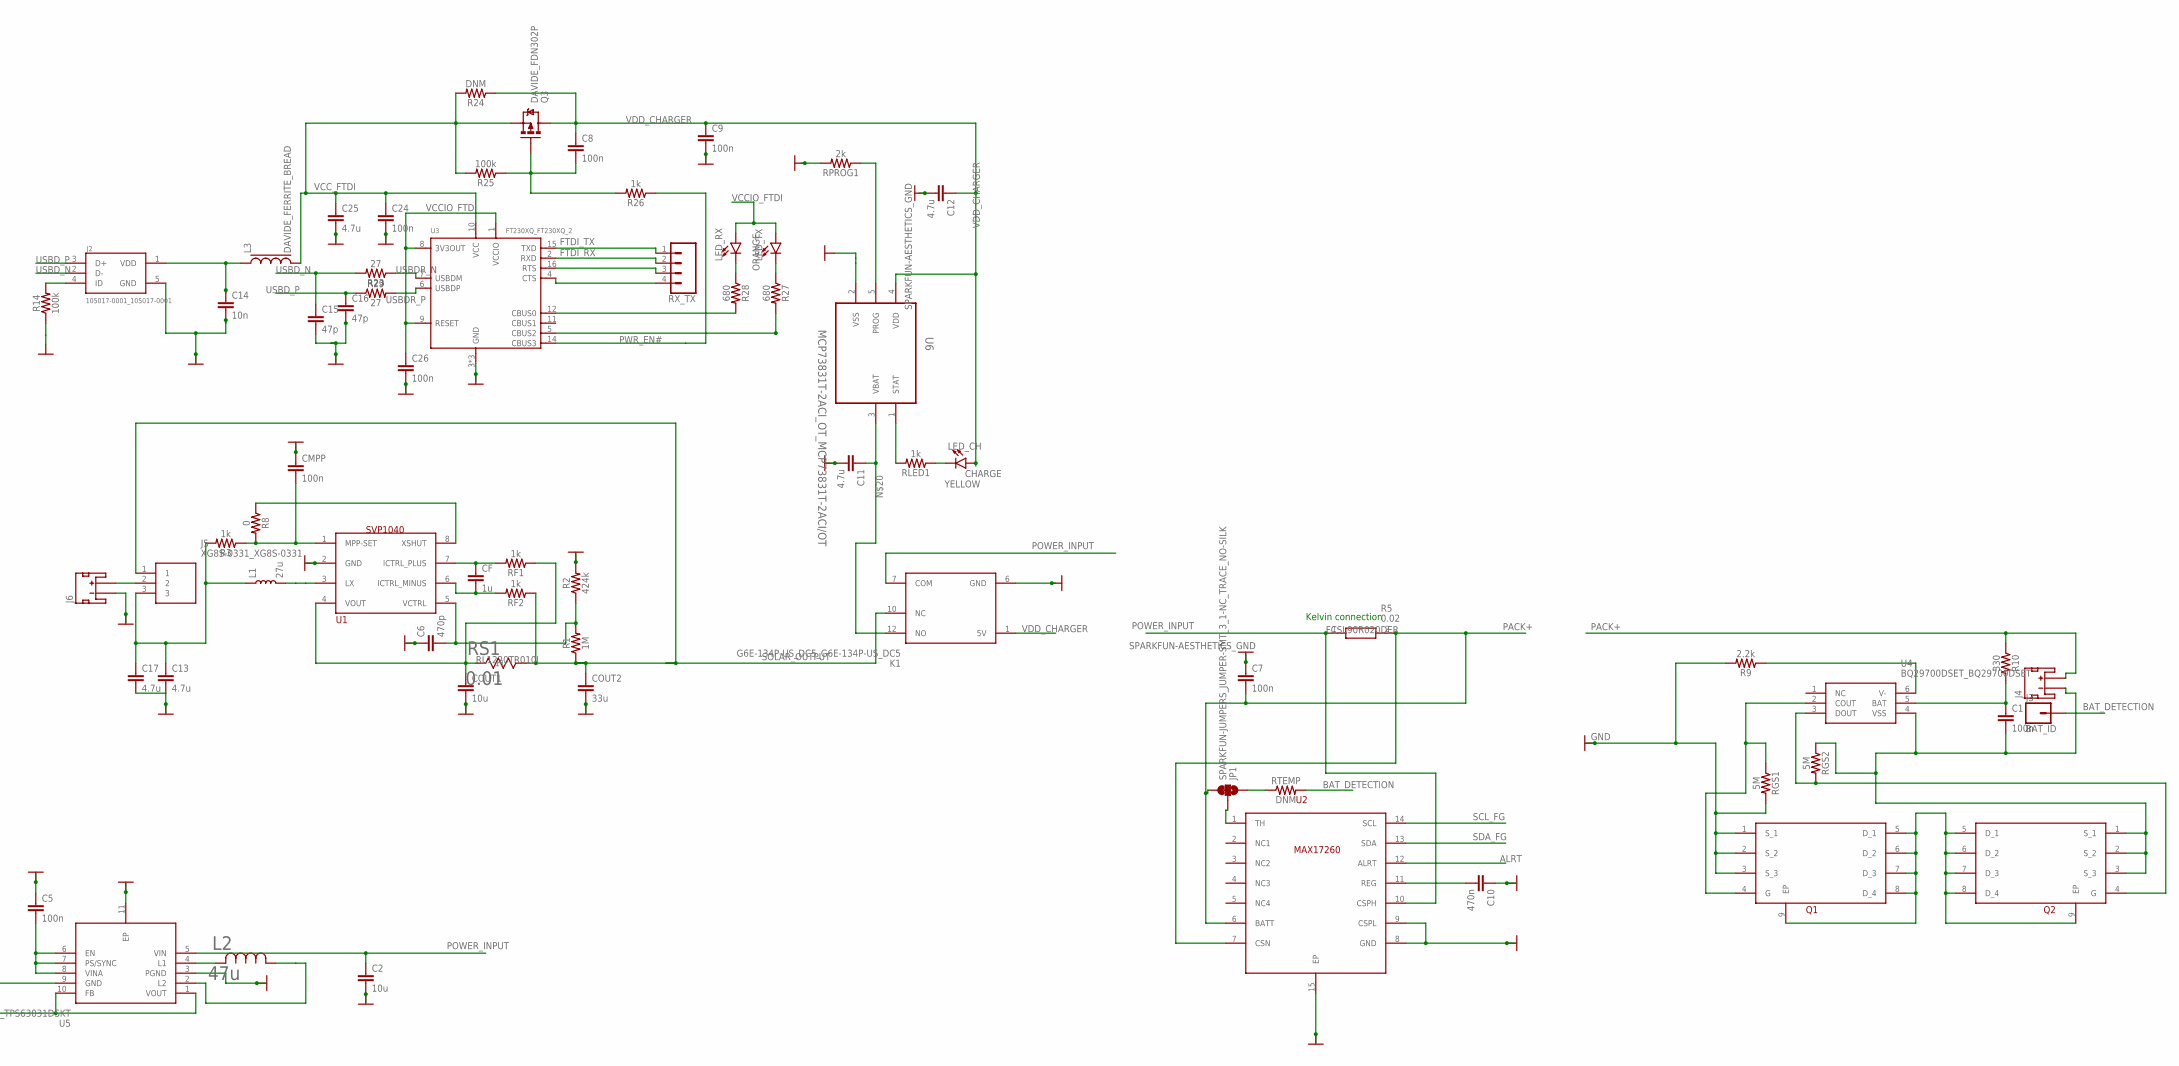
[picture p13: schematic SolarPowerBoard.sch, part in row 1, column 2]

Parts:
B1: POWERSOL_CC2650LAUNCHPAD; POWERSOL_SEPS_RB; MPN LAUNCHXL-CC2650
B2: POWERSOL_PCA10040NORDIC; POWERSOL_SEPS_BB
C1, C5, C7, C8, C9, C24, C26: 100n; SPARKFUN-CAPACITORS_0805; MPN TPSP106M010R2000
C2, C3, C4: 10u; SPARKFUN-CAPACITORS_0805; MPN TPSP106M010R2000
C6: 470p; SPARKFUN-CAPACITORS_0805; MPN TPSP106M010R2000
C10: 470n; SPARKFUN-CAPACITORS_0805; MPN TPSP106M010R2000
C11, C12, C13, C17, C25: 4.7u; SPARKFUN-CAPACITORS_0805; MPN TPSP106M010R2000
C14: 10n; SPARKFUN-CAPACITORS_0805; MPN TPSP106M010R2000
C15, C16: 47p; SPARKFUN-CAPACITORS_0805; MPN TPSP106M010R2000
CF: 1u; SPARKFUN-CAPACITORS_0805; MPN TPSP106M010R2000
CMPP: 100n; SPARKFUN-CAPACITORS_0805; MPN TPSP106M010R2000
COUT1: 10u; SPARKFUN-CAPACITORS_0805; MPN TPSP106M010R2000
COUT2: 33u; SPARKFUN-CAPACITORS_0805; MPN TPSP106M010R2000
J2: 105017-0001_105017-0001; 105017-0001_MOLEX_105017-0001; MPN 105017-0001
J3: BAT_ID; SPARKFUN-CONNECTORS_1X01
J4, J6: SOLARCOMPONENTS_JST_2MM_MALE; SOLARCOMPONENTS_JST-2-SMD
J5: XG8S-0331_XG8S-0331; XG8S-0331_HDRV3W70P0X254_1X3_760X280X680
JP1: SPARKFUN-JUMPERS_JUMPER-SMT_3_1-NC_TRACE_NO-SILK; SPARKFUN-JUMPERS_SMT-JUMPER_3_1-NC_TRACE_NO-SILK
K1: G6E-134P-US_DC5_G6E-134P-US_DC5; G6E-134P-US_DC5_DIP762W60P254L1595H800Q12N
L1: 27u; AXIAL-14MM; MPN B82144F2273K000
L2: 47u; SRN3010-470M_IND_BOURNS_SRN3010; MPN SRN3010-470M
L3: DAVIDE_FERRITE_BREAD; DAVIDE_0805:1; MPN MI0805K601R-10
LED_CH: LED0603; LED-0603
LED_RX: LED0603; LED-0603
LED_TX: LED0603; LED-0603
Q1, Q2: SOLARCOMPONENTS_CSD16406Q3; SOLARCOMPONENTS_CSD16327; MPN CSD16406Q3
Q3: DAVIDE_FDN302P; DAVIDE_SOT23-3
R1: 1M; SPARKFUN-RESISTORS_0805; MPN RLP73N2AR30JTD
R2: 424k; SPARKFUN-RESISTORS_0805; MPN RLP73N2AR30JTD
R3, R26: 1k; SPARKFUN-RESISTORS_0805; MPN RLP73N2AR30JTD
R4, R14, R25: 100k; SPARKFUN-RESISTORS_0805; MPN RLP73N2AR30JTD
R5: 0.02; FCSL90R020DER_FOOTPRINT
R8: 0; SPARKFUN-RESISTORS_0805; MPN RLP73N2AR30JTD
R9: 2.2k; SPARKFUN-RESISTORS_0805; MPN RLP73N2AR30JTD
R10: 330; SPARKFUN-RESISTORS_0805; MPN RLP73N2AR30JTD
R23, R29: 27; SPARKFUN-RESISTORS_0805; MPN RLP73N2AR30JTD
R24: DNM; SPARKFUN-RESISTORS_0805; MPN RLP73N2AR30JTD
R27, R28: 680; SPARKFUN-RESISTORS_0805; MPN RLP73N2AR30JTD
RES_SEL: POWERSOL_JUMPER-SMT_3_0_SILK; POWERSOL_SMT-JUMPER_3_0_NC_TRACE_SILK
RF1, RF2: 1k; SPARKFUN-RESISTORS_0805; MPN RLP73N2AR30JTD
RGPIO1, RGPIO2, RGPIO3, RGPIO4: DNM; SPARKFUN-RESISTORS_0805; MPN RLP73N2AR30JTD
RGS1, RGS2: 5M; SPARKFUN-RESISTORS_0805; MPN RLP73N2AR30JTD
RLED1: 1k; SPARKFUN-RESISTORS_0805; MPN RLP73N2AR30JTD
RPROG1: 2k; SPARKFUN-RESISTORS_0805; MPN RLP73N2AR30JTD
RRX: 1k; SPARKFUN-RESISTORS_0805; MPN RLP73N2AR30JTD
RS1: 0.01; RL1220T-R010-J_RES_1220
RTEMP: DNM; SPARKFUN-RESISTORS_0805; MPN RLP73N2AR30JTD
RX_TX: SPARKFUN-CONNECTORS_CONN_04; SPARKFUN-CONNECTORS_1X04
SCL: POWERSOL_JUMPER-SMT_3_0_SILK; POWERSOL_SMT-JUMPER_3_0_NC_TRACE_SILK
SCL_SDA: SPARKFUN-CONNECTORS_CONN_02; SPARKFUN-CONNECTORS_1X02
SDA: POWERSOL_JUMPER-SMT_3_0_SILK; POWERSOL_SMT-JUMPER_3_0_NC_TRACE_SILK
U1: SOLARCOMPONENTS_SVP1040; SOLARCOMPONENTS_TSSOP-8
U2: SOLARCOMPONENTS_MAX17260; SOLARCOMPONENTS_SON40P300X300X80-15N; MPN MAX17260SEWL+
U3: FT230XQ_FT230XQ_2; FT230XQ_QFN16; MPN FT230XQ-R
U4: BQ29700DSET_BQ29700DSET; BQ29700DSET_SON50P150X150X80-6N; MPN BQ29700DSET
U5: TPS63031DSKT_TPS63031DSKT; TPS63031DSKT_SON50P250X250X80-11N; MPN TPS63031DSKT
U6: MCP73831T-2ACI_OT_MCP73831T-2ACI/OT; MCP73831T-2ACI_OT_SOT95P280X145-5N
U7: 74XX-LITTLE-DE_74AHC1G08DCK; 74XX-LITTLE-DE_SC70-5; MPN SN74AHC1G08DCKR

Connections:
ALRT: B1.DIO15, U2.12 (ALRT)
BAT_DETECTION: J3.1, RTEMP.2
DIO1_RESERVED: B1.DIO1-RESET, RES_SEL.3
DIO22: B1.DIO22, RES_SEL.1
DP5_UART_FTDI_RX: RRX.1, U7.4 (O)
FTDI_RX: RRX.2, RX_TX.2, U3.2 (RXD)
FTDI_TX: RX_TX.1, U3.15 (TXD)
GND: B1.GND, B1.GND@1 (GND), B2.GND, B2.GND@1 (GND), B2.GND@2 (GND), C2.2, C3.2, C4.2, C5.1, C6.1, C7.1, C9.2, C10.1, C11.2, C12.2, C13.2, C14.2, C15.2, C16.2, C17.2, C24.2, C25.2, C26.2, CMPP.1, COUT1.2, COUT2.2, J2.5 (GND), J6.1 (-), J6.P$1 (-), K1.6 (GND), Q1.1 (S_1), Q1.2 (S_2), Q1.3 (S_3), R2.2, R9.2, R14.1, RGS1.2, RPROG1.2, U1.2 (GND), U2.8 (GND), U2.9 (CSPL), U2.15 (EP), U3.3 (GND), U3.13 (GND), U3.17 (GND), U5.3 (PGND), U5.9 (GND), U5.11 (EP), U6.2 (VSS), U7.3 (GND)
GPIO1: B2.PO.03, RGPIO1.1
GPIO2: B2.PO.04, RGPIO2.1
GPIO3: B2.PO.28, RGPIO3.1
GPIO4: B2.PO.29, RGPIO4.1
unnamed: C13.1, C17.1, J5.3, L1.P$1 (1), R3.2
unnamed: RPROG1.1, U6.5 (PROG)
unnamed: CMPP.2, R3.1, R8.2, U1.1 (MPP-SET)
unnamed: R8.1, U1.8 (XSHUT)
unnamed: COUT1.1, RF1.1, RS1.1 (11), U1.4 (VOUT)
unnamed: CF.1, RF1.2, U1.7 (ICTRL_PLUS)
unnamed: CF.2, RF2.2, U1.6 (ICTRL_MINUS)
unnamed: L2.2, U5.4 (L1)
unnamed: LED_CH.C, RLED1.1
unnamed: C6.2, R1.2, R2.1, U1.5 (VCTRL)
unnamed: C5.2, U5.6 (EN), U5.7 (PS/SYNC), U5.8 (VINA)
unnamed: L2.1, U5.2 (L2)
unnamed: RLED1.2, U6.1 (STAT)
unnamed: Q1.5 (D_1), Q1.6 (D_2), Q1.7 (D_3), Q1.8 (D_4), Q1.9 (EP), Q2.5 (D_1), Q2.6 (D_2), Q2.7 (D_3), Q2.8 (D_4), Q2.9 (EP)
unnamed: Q1.4 (G), RGS1.1, U4.2 (COUT)
unnamed: J5.2, J6.2 (+), J6.P$2 (+)
unnamed: JP1.2, U2.1 (TH)
unnamed: L1.P$2 (2), U1.3 (LX)
unnamed: C1.2, J4.1 (-), J4.P$1 (-), Q2.1 (S_1), Q2.2 (S_2), Q2.3 (S_3), RGS2.1, U4.4 (VSS)
unnamed: C11.1, K1.12 (NO), U6.3 (VBAT)
unnamed: JP1.1, RTEMP.1
unnamed: Q2.4 (G), RGS2.2, U4.3 (DOUT)
unnamed: C1.1, R10.2, U4.5 (BAT)
unnamed: C14.1, J2.1 (VDD), L3.1
unnamed: C8.2, Q3.1 (G), R25.1, R26.2
unnamed: J2.4 (ID), R14.2
unnamed: B1.MOSI, RGPIO1.2
unnamed: R9.1, U4.6 (V-)
unnamed: B1.MISO, RGPIO2.2
unnamed: R28.2, U3.12 (CBUS0)
unnamed: LED_RX.C, R28.1
unnamed: B1.BTN1, RGPIO3.2
unnamed: RX_TX.3, U3.16 (RTS)
unnamed: RX_TX.4, U3.4 (CTS)
unnamed: B1.SDA_FG, SDA.3
unnamed: B1.SCL_FG, SCL.1
unnamed: B2.SDA_FG, SDA.1
unnamed: B2.SCL_FG, SCL.3
unnamed: B1.BTN2, RGPIO4.2
unnamed: LED_TX.C, R27.1
unnamed: R27.2, U3.5 (CBUS2)
unnamed: C10.2, U2.11 (REG)
NRF_RESET: B2.DIO1-RESET, RES_SEL.2
PACK+: C7.2, J4.2 (+), J4.P$2 (+), JP1.3, R5.2, R10.1, U2.6 (BATT), U2.7 (CSN)
PO.22(CTS)-DIO18(RTS): B1.PO.22(CTS)-DIO18(RT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, B2.PO.22(CTS)-DIO18(RT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
PO.23(RTS)-DIO19(CTS): B1.PO.23(RTS)-DIO19(CT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, B2.PO.23(RTS)-DIO19(CT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
PO.24(TX)-DIO2(RX): B1.PO.24(TX)-DIO2(RX), B2.PO.24(TX)-DIO2(RX), U7.2 (I1)
PO.25(RX)-DIO3(TX): B1.PO.25(RX)-DIO3(TX), B2.PO.25(RX)-DIO3(TX), R4.2, U7.1 (I0)
POWER_INPUT: C2.1, K1.7 (COM), R5.1, U2.10 (CSPH), U5.5 (VIN)
PWR_EN#: R26.1, U3.14 (CBUS3)
SCL_FG: SCL.2, SCL_SDA.2, U2.14 (SCL)
SDA_FG: SCL_SDA.1, SDA.2, U2.13 (SDA)
SOLAR_OUTPUT: COUT2.1, J5.1, K1.10 (NC), R1.1, RF2.1, RS1.2 (22)
USBDR_N: R23.1, U3.7 (USBDM)
USBDR_P: R29.2, U3.6 (USBDP)
USBD_N: C15.1, J2.2 (D-), R23.2
USBD_P: C16.1, J2.3 (D+), R29.1
VCCIO_FTDI: C26.1, LED_RX.A, LED_TX.A, U3.1 (VCCIO), U3.8 (3V3OUT), U3.9 (RESET), U7.5 (VCC)
VCC_FTDI: C24.1, C25.1, L3.2, Q3.2 (S), R24.2, R25.2, U3.10 (VCC)
VDD: B1.VDD, B2.VDD@2 (VDD), C3.1, C4.1, R4.1, U5.1 (VOUT), U5.10 (FB)
VDD_CHARGER: C8.1, C9.1, C12.1, K1.1 (5V), LED_CH.A, Q3.3 (D), R24.1, U6.4 (VDD)

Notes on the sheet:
Kelvin connection

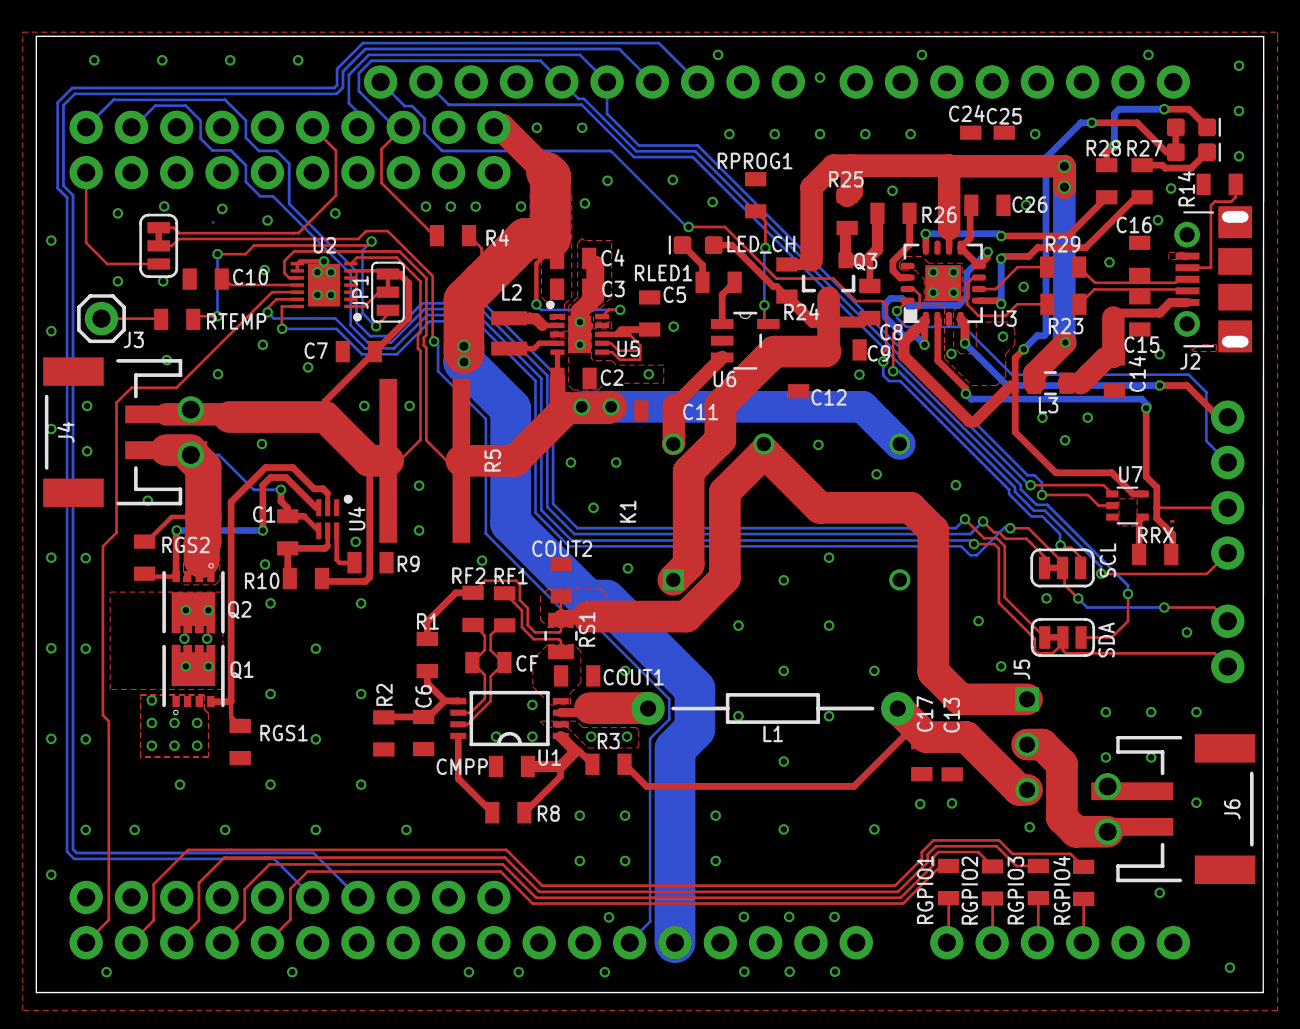
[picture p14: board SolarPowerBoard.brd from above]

Board: 2 copper layers, 68.8 x 53.6 mm, 83 parts (1 on the bottom side), 73 nets.

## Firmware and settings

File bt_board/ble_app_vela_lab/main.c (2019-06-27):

/**
 * Copyright (c) 2016 - 2017, Nordic Semiconductor ASA
 * 
 * All rights reserved.
 * 
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
 * 3. Neither the name of Nordic Semiconductor ASA nor the names of its
 *    contributors may be used to endorse or promote products derived from this
 *    software without specific prior written permission.
 * 
 * 4. This software, with or without modification, must only be used with a
 *    Nordic Semiconductor ASA integrated circuit.
 * 
 * 5. Any software provided in binary form under this license must not be reverse
 *    engineered, decompiled, modified and/or disassembled.
 * 
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
 */
/**@cond To Make Doxygen skip documentation generation for this file.
 * @{
 */

#include <stdbool.h>
#include <stdint.h>
#include <string.h>
#include <stdio.h>


#include "sdk_config.h"
//#include "boards.h"
#include "nrf.h"
#include "ble.h"
#include "ble_hci.h"
#include "nordic_common.h"
#include "nrf_gpio.h"
#include "bsp_btn_ble.h"
#include "ble_advdata.h"
#include "ble_srv_common.h"
#include "nrf_sdh.h"
#include "nrf_sdh_ble.h"
#include "nrf_ble_gatt.h"
#include "app_timer.h"
#include "app_error.h"
#include "nrf_soc.h"
#include "nrf_delay.h"
//#include "nrf_cli.h"
//#include "nrf_cli_rtt.h"
//#include "nrf_cli_uart.h"

#include "uart_util.h"
#include "constraints.h"
#include "sequential_procedures.h"
#if defined(ENABLE_TOF) && ENABLE_TOF==1
#include "ble_db_discovery.h"
#include "ifs_tof.h"
#include "ble_dists.h"
#if defined(ENABLE_GATT) && ENABLE_GATT==1
#include "nrf_ble_gatt.h"
NRF_BLE_GATT_DEF(m_gatt);                   /**< GATT module instance. */
BLE_DB_DISCOVERY_DEF(m_ble_db_discovery);   /**< DB discovery module instance. */
BLE_DISTS_DEF(m_dists);                                              /**< Heart rate service instance. */
#endif
#endif

#include "nrf_log_default_backends.h"

#define  NRF_LOG_MODULE_NAME application
#include "nrf_log.h"
#include "nrf_log_ctrl.h"
NRF_LOG_MODULE_REGISTER();
#define PRINTF(...) NRF_LOG_DEBUG(__VA_ARGS__); /*\
                    NRF_LOG_PROCESS()*/


#define CONN_INTERVAL_DEFAULT           (uint16_t)(MSEC_TO_UNITS(10, UNIT_1_25_MS))    /**< Default connection interval used at connection establishment by central side. */

#define CONN_INTERVAL_MIN               (uint16_t)(MSEC_TO_UNITS(10, UNIT_1_25_MS))    /**< Minimum acceptable connection interval, in 1.25 ms units. */
#define CONN_INTERVAL_MAX               (uint16_t)(MSEC_TO_UNITS(25, UNIT_1_25_MS))    /**< Maximum acceptable connection interval, in 1.25 ms units. */
#define CONN_SUP_TIMEOUT                (uint16_t)(MSEC_TO_UNITS(100,  UNIT_10_MS))    /**< Connection supervisory timeout (4 seconds). */
#define SLAVE_LATENCY                   0                                               /**< Slave latency. */

#define READY_LED                       1 << BSP_BOARD_LED_0
#define PROGRESS_LED                    1 << BSP_BOARD_LED_1
#define SCAN_ADV_LED                    1 << BSP_BOARD_LED_2
#define ERROR_LED                       1 << BSP_BOARD_LED_3

#define LED_BLINK_TIMEOUT_MS			50
#define LP_LED_INTERVAL					5000

#define TOGGLE_SCAN_BUTTON             	BSP_BUTTON_2                                    /**< Button to press at beginning of the test to indicate that this board is connected to the PC and takes input from it via the UART. */
#define TOGGLE_ADV_BUTTON           	BSP_BUTTON_3                                    /**< Button to press at beginning of the test to indicate that this board is standalone (automatic behavior). */
#define TOGGLE_TOF_BUTTON               BSP_BUTTON_0

#define BUTTON_DETECTION_DELAY          APP_TIMER_TICKS(50)                             /**< Delay from a GPIOTE event until a button is reported as pushed (in number of timer ticks). */

#define APP_BLE_CONN_CFG_TAG            1                                               /**< A tag that refers to the BLE stack configuration. */
#define APP_BLE_OBSERVER_PRIO           1                                               /**< Application's BLE observer priority. You shouldn't need to modify this value. */
#define L2CAP_HDR_LEN                   4                                               /**< L2CAP header length. */

#define USE_NANOSECOND
#define nENABLE_PHY_UPDATE

#define MAXIMUM_NETWORK_SIZE			MAX_NUMBER_OF_BT_BEACONS//NRF_SDH_BLE_TOTAL_LINK_COUNT
#define MAXIMUM_NUMBER_OF_PERIPH_CONN	NRF_SDH_BLE_PERIPHERAL_LINK_COUNT
#define MAXIMUM_NUMBER_OF_CENTRAL_CONN	6//IFT_TOF_MAX_NUM_OF_CENTRAL_LINKS

#define ENABLE_AMTv

#define DEFAULT_ACTIVE_SCAN             1     //boolean
#define DEFAULT_SCAN_INTERVAL           3520       /**< Scan interval between 0x0004 and 0x4000 in 0.625 ms units (2.5 ms to 10.24 s). */
#define DEFAULT_SCAN_WINDOW             1920     /**< Scan window between 0x0004 and 0x4000 in 0.625 ms units (2.5 ms to 10.24 s). */
#define DEFAULT_TIMEOUT                 0
#define PERIODIC_TIMER_INTERVAL         APP_TIMER_TICKS(1000)
#define NODE_TIMEOUT_DEFAULT_MS			(uint32_t)60000

#define MIN_REPORT_TIMEOUT_MS					1000

#define APP_TIMER_MS(TICKS)  (uint32_t)(ROUNDED_DIV (((uint64_t)TICKS * ( ( (uint64_t)APP_TIMER_CONFIG_RTC_FREQUENCY + 1 ) * 1000 )) , (uint64_t)APP_TIMER_CLOCK_FREQ ))

#define UART_ACK_DELAY_US               2000

APP_TIMER_DEF(m_periodic_timer_id);
APP_TIMER_DEF(m_report_timer_id);
APP_TIMER_DEF(m_led_blink_timer_id);
APP_TIMER_DEF(m_lp_led_timer_id);

//NRF_CLI_DEF(m_cli_rtt,  "throughput example:~$ ", &cli_rtt.transport,  '\n', 4);
typedef enum
{
    CLIMB_BEACON,
    EDDYSTONE_BEACON,
    NORDIC_BEACON,  //not used for now
    IFS_TOF_DEVICE,  //not used for now
	UNKNOWN_TYPE,
} node_type_t;

typedef enum
{
    NOT_SELECTED = 0x00,
    BOARD_TESTER,
    BOARD_DUMMY,
} board_role_t;

typedef struct
{
    uint16_t        att_mtu;                    /**< GATT ATT MTU, in bytes. */
    uint16_t        conn_interval;              /**< Connection interval expressed in units of 1.25 ms. */
    ble_gap_phys_t  phys;                       /**< Preferred PHYs. */
    bool            data_len_ext_enabled;       /**< Data length extension status. */
    bool            conn_evt_len_ext_enabled;   /**< Connection event length extension status. */
#ifdef ENABLE_AMT
    bool            transmit_data;				/**< Whether to transmit data during the test */
#endif
    bool 			continuous_test;			/**< if set to true the test keeps going on (works without data stream) */
} test_params_t;

typedef struct
{
    uint8_t    p_data[31];      /**< Pointer to data. */
    uint16_t   len;    /**< Length of data. */
} s_data_t;

typedef struct
{
    uint16_t  			conn_handle;
    uint8_t             local_role;
	ble_gap_addr_t 		bd_address;
	s_data_t			adv_data;
	s_data_t			scan_data;
	uint32_t			first_contact_ticks;
	uint32_t 			last_contact_ticks;
	int8_t				last_rssi;
	int8_t				max_rssi;
	uint8_t				beacon_msg_count;
	uint8_t				namespace_id[EDDYSTONE_NAMESPACE_ID_LENGTH];
	uint8_t				instance_id[EDDYSTONE_INSTANCE_ID_LENGTH];
	node_type_t			node_type;
} node_t;


#ifdef ENABLE_AMT
NRF_BLE_GATT_DEF(m_gatt);                   /**< GATT module instance. */
BLE_DB_DISCOVERY_DEF(m_ble_db_discovery);   /**< DB discovery module instance. */

static nrf_ble_amtc_t     m_amtc;
static nrf_ble_amts_t     m_amts;
NRF_SDH_BLE_OBSERVER(m_amtc_ble_obs, BLE_AMTC_BLE_OBSERVER_PRIO, nrf_ble_amtc_on_ble_evt, &m_amtc);
NRF_SDH_BLE_OBSERVER(m_amts_ble_obs, BLE_AMTS_BLE_OBSERVER_PRIO, nrf_ble_amts_on_ble_evt, &m_amts);
#endif

static bool volatile m_conn_interval_configured;

//static uint16_t m_conn_handle = BLE_CONN_HANDLE_INVALID;    /**< Handle of the current BLE connection .*/
//static uint8_t m_gap_role     = BLE_GAP_ROLE_INVALID;       /**< BLE role for this connection, see @ref BLE_GAP_ROLES */
//static ble_gap_addr_t m_remote_address;
// Name to use for advertising and connection.

static char const m_target_periph_name[] = DEVICE_NAME;
static char const m_target_periph_name_alt1[] = {'C',
                                                'L',
                                                'I',
                                                'M',
                                                'B',
                                                'C'};

static char const m_target_periph_name_alt2[] = {'C',
                                                'L',
                                                'I',
                                                'M',
                                                'B',
                                                'L'};



bool m_ready_received = false, m_tx_error = false;
static uint32_t m_periodic_report_timeout = 0;
uint8_t stop = 0;
uint32_t beacon_timeout_ms = NODE_TIMEOUT_DEFAULT_MS;
//uint32_t blinking_led_bit_map;

#if defined(ENABLE_TOF) && ENABLE_TOF==1
static uint8_t m_no_of_central_links = 0;
static uint8_t m_no_of_peripheral_links = 0;
static ifs_tof_t m_ifs_tof[MAXIMUM_NUMBER_OF_CENTRAL_CONN];
static uint32_t ifs_offset_ticks;
static bool allow_new_connections = false;
static bool pending_connection_req = false;

uint16_t total_number_of_connection_events;
bool m_ifs_tof_active=false;

//NRF_SDH_BLE_OBSERVER(m_ifs_tof_bel_obs, BLE_IFS_TOF_BLE_OBSERVER_PRIO, ifs_tof_on_ble_evt, NULL);
#endif
bool m_scan_active = false, m_advertising_active = false;

static node_t m_network[MAXIMUM_NETWORK_SIZE];

// Test parameters.
// Settings like ATT MTU size are set only once on the dummy board.
// Make sure that defaults are sensible.
static test_params_t m_test_params =
{
    .att_mtu                  = NRF_SDH_BLE_GATT_MAX_MTU_SIZE,
    .conn_interval            = CONN_INTERVAL_DEFAULT,
    .data_len_ext_enabled     = true,
    .conn_evt_len_ext_enabled = true,
#ifdef ENABLE_AMT
	.transmit_data			  = false,
#endif
	.continuous_test		  = true,
    // Only symmetric PHYs are supported.
#if defined(S140)
    .phys.tx_phys             = BLE_GAP_PHY_2MBPS | BLE_GAP_PHY_1MBPS | BLE_GAP_PHY_CODED,
    .phys.rx_phys             = BLE_GAP_PHY_2MBPS | BLE_GAP_PHY_1MBPS | BLE_GAP_PHY_CODED,
#else
    .phys.tx_phys             = BLE_GAP_PHY_1MBPS,//BLE_GAP_PHY_2MBPS | BLE_GAP_PHY_1MBPS,
    .phys.rx_phys             = BLE_GAP_PHY_1MBPS,//BLE_GAP_PHY_2MBPS | BLE_GAP_PHY_1MBPS,
#endif
};

// Scan parameters requested for scanning and connection.
static ble_gap_scan_params_t m_scan_param =
{
    .active         = 0x01,
    .interval       = SCAN_INTERVAL,
    .window         = SCAN_WINDOW,
    .use_whitelist  = 0x00,
    .adv_dir_report = 0x00,
    .timeout        = 0x0000, // No timeout.
};

// Connection parameters requested for connection.
static ble_gap_conn_params_t m_conn_param =
{
    .min_conn_interval = CONN_INTERVAL_MIN,   // Minimum connection interval.
    .max_conn_interval = CONN_INTERVAL_MAX,   // Maximum connection interval.
    .slave_latency     = SLAVE_LATENCY,       // Slave latency.
    .conn_sup_timeout  = CONN_SUP_TIMEOUT     // Supervisory timeout.
};

uint32_t adv_data_to_string(s_data_t *p_adv_data, char* p_str, uint8_t max_len);
uint32_t bd_addr_to_string(const ble_gap_addr_t *p_addr, char* p_str, uint8_t max_len);

//application helpers
uint32_t add_node_to_report_payload(node_t *m_network, uint8_t* report_payload, uint16_t max_size);
uint8_t send_neighbors_report(void);
void cancel_ongoing_report(void);
void send_pong(uart_pkt_t* p_packet);
uint8_t send_ping(void);
uint8_t send_ready(void);

//uart communication helpers
extern void uart_util_rx_handler(uart_pkt_t* p_packet);
extern void uart_util_ack_tx_done(void);
extern void uart_util_ack_error(ack_wait_t* ack_wait_data);

//ToF
#if defined(ENABLE_TOF) && ENABLE_TOF==1
static uint32_t calculate_ifs_offset(ble_gap_phys_t actual_phy);
static void tof_results_print(ifs_tof_t * p_ctx);
#endif

//BT neighbors list management
void on_scan_response(ble_gap_evt_adv_report_t const * p_adv_report);
void on_adv(ble_gap_evt_adv_report_t const * p_adv_report);
void network_maintainance_check(void);
uint32_t get_time_since_last_contact(node_t *p_node);
node_t* get_network_pos_by_bdaddr(const ble_gap_addr_t *target_addr);
node_t* get_network_pos_by_conn_handle(uint16_t target_conn_h);
uint8_t is_position_free(node_t *p_node);
node_t* get_first_free_network_pos(void);
static void remove_node_from_network(node_t* p_node);
static node_t* add_node_to_network(const ble_gap_evt_t *p_conn_evt, const ble_gap_evt_adv_report_t *p_adv_evt, node_type_t node_type);
static node_t* update_node(const ble_gap_evt_t *p_conn_evt, const ble_gap_evt_adv_report_t *p_adv_evt, node_t * p_node);
static void reset_node(node_t* p_node);
static void reset_network(void);
static void disconnect_all_ifs_tof_devices(void);

//application timers helpers/callbacks
void application_timers_start(void);
void start_periodic_report(uint32_t timeout_ms);
static void report_timeout_handler(void * p_context);
static void periodic_timer_timeout_handler(void * p_context);
static void led_timeout_handler(void * p_context);
static void lp_led_timeout_handler(void * p_context);
void blink_led(uint32_t led_idx, uint32_t blink_timeout);

//bt callbacks/helpers
static void ble_stack_init(void);
static void gap_params_init(void);
static void advertising_data_set(void);
void preferred_phy_set(ble_gap_phys_t * p_phy);
void conn_interval_set(uint16_t value);
#if defined(ENABLE_TOF) && ENABLE_TOF==1
static void db_disc_evt_handler(ble_db_discovery_evt_t * p_evt);
#endif
static void ble_evt_handler(ble_evt_t const * p_ble_evt, void * p_context);
static void on_ble_gap_evt_disconnected(ble_gap_evt_t const * p_gap_evt);
static void on_ble_gap_evt_connected(ble_gap_evt_t const * p_gap_evt);
static void on_ble_gap_evt_adv_report(ble_gap_evt_t const * p_gap_evt);
static void scan_stop(void);
static void scan_start(void);
static void advertising_stop(void);
static void advertising_start(void);
#if defined(ENABLE_TOF) && ENABLE_TOF==1
static void ble_tof_start(void);
static void ble_tof_stop(void);
#endif
static void set_scan_params(uint8_t scan_active, uint16_t scan_interval, uint16_t scan_window, uint16_t scan_timeout);
char const * phy_str(ble_gap_phys_t phys);
static uint32_t adv_report_parse(uint8_t type, data_t * p_advdata, data_t * p_typedata);
static uint32_t get_adv_name(ble_gap_evt_adv_report_t const * p_adv_report, data_t * dev_name);
static uint32_t get_adv_16bit_uuid(ble_gap_evt_adv_report_t const * p_adv_report, data_t * uuid_data);
static uint32_t get_adv_service_data(ble_gap_evt_adv_report_t const * p_adv_report, data_t * service_data, uint16_t target_uuid);
uint32_t get_eddystone_frame(ble_gap_evt_adv_report_t const * p_adv_report, data_t * dev_name);
uint32_t get_adv_manufacturer_specific_data(ble_gap_evt_adv_report_t const * p_adv_report, data_t * manufacturer_data, uint16_t target_manuf_uuid);
static bool is_known_name(ble_gap_evt_adv_report_t const * p_adv_report, char const * name_to_find);
bool is_16bit_uuid_included(ble_gap_evt_adv_report_t const * p_adv_report, uint16_t target_uuid);
static bool is_known_eddystone(ble_gap_evt_adv_report_t const * p_adv_report, uint8_t const * namespace_to_find);

//hardware init/callbacks/helpers
static void initialize_leds(void);
static void initialize_uart(void);
static void timer_init(void);
static void buttons_init(void);
static void buttons_enable(void);
static void button_evt_handler(uint8_t pin_no, uint8_t button_action);

//system
static void wait_for_event(void);

#if defined(ENABLE_TOF) && ENABLE_TOF==1
void ifs_tof_evt_handler(ifs_tof_evt_t * p_evt);
static bool is_link_present(ble_gap_evt_adv_report_t const * p_adv_report);
#endif

PROCEDURE(ping, &send_ping);
PROCEDURE(ready, &send_ready);
PROCEDURE_VAR_LEN(ble_report, &send_neighbors_report);

static uint8_t start_procedure(procedure_t *m_procedure){
    return sequential_procedure_start(m_procedure, uart_util_is_waiting_ack()); //if we are waiting an ack start use the delayed start
}

uint32_t bd_addr_to_string(const ble_gap_addr_t *p_addr, char* p_str, uint8_t max_len) {
//	return sprintf(p_str, "%02X:%02X:%02X:%02X:%02X:%02X", p_addr->addr[5], p_addr->addr[4], p_addr->addr[3], p_addr->addr[2], p_addr->addr[1],
//			p_addr->addr[0]);
	if (p_addr == NULL) {
		return 0;
	}
	uint8_t str_i = 0;
	for (int i = 0; i < 6 && str_i + 1 <= max_len; i++) {
		p_str[str_i++] = to_hex((p_addr->addr[5 - i] >> 4) & 0x0F);
		p_str[str_i++] = to_hex((p_addr->addr[5 - i]) & 0x0F);
	}
	return str_i;
}

uint32_t adv_data_to_string(s_data_t *p_adv_data, char* p_str, uint8_t max_len) {
	if (p_adv_data == NULL) {
		return 0;
	}
	uint8_t str_i = 0;
	for (int i = 0; i < p_adv_data->len && str_i + 1 <= max_len; i++) {
		p_str[str_i++] = to_hex((p_adv_data->p_data[i] >> 4) & 0x0F);
		p_str[str_i++] = to_hex((p_adv_data->p_data[i]) & 0x0F);
	}
	return str_i;
}

uint32_t add_node_to_report_payload(node_t *p_node, uint8_t* report_payload, uint16_t max_size) {
	if (p_node == NULL || report_payload == NULL || max_size < SINGLE_NODE_REPORT_SIZE) {
		return 0;
	}

	uint16_t idx = 0;

	//add ID
	memcpy(&report_payload[idx], p_node->instance_id, EDDYSTONE_INSTANCE_ID_LENGTH);
	idx += EDDYSTONE_INSTANCE_ID_LENGTH;

	//add last rssi
	report_payload[idx++] = (uint8_t) p_node->last_rssi;

	//add max rssi
	report_payload[idx++] = (uint8_t) p_node->max_rssi;

	//add packet counter
	report_payload[idx++] = p_node->beacon_msg_count;
	return idx;
}

uint8_t send_neighbors_report(void) {

	static uint16_t n = 0;
	bool pkt_full = false;
	uint8_t report_payload[UART_PKT_PAYLOAD_MAX_LEN_SYMB];
	uint16_t payload_free_from = 0;

	uart_pkt_t packet;

	if(!sequential_procedure_is_this_running(&ble_report)){ //sanity check, if the report procedure was not active (maybe it was cancelled) reset n to zero
	    n=0;
	}

	packet.payload.p_data = report_payload;
	if (n == 0) {	//if this is the first packet of the report the type will end with the '_start'
		packet.type = uart_resp_bt_neigh_rep_start;
	} else {		//otherwise it will be '_more'
		packet.type = uart_resp_bt_neigh_rep_more;
	}

	while (n < MAXIMUM_NETWORK_SIZE && pkt_full == false) {
		if (UART_PKT_PAYLOAD_MAX_LEN_SYMB - payload_free_from > SINGLE_NODE_REPORT_SIZE) {
			if (!is_position_free(&m_network[n])) {
			    if(m_network[n].node_type!=IFS_TOF_DEVICE){
			        uint32_t occupied_size = add_node_to_report_payload(&m_network[n], &report_payload[payload_free_from], UART_PKT_PAYLOAD_MAX_LEN_SYMB - payload_free_from);
			        payload_free_from += occupied_size;
			    }
			}
			n++;
		} else {
			pkt_full = true;
			PRINTF("Report packet full!!\n");
		}
	}

	packet.payload.data_len = payload_free_from;
	if (n >= MAXIMUM_NETWORK_SIZE) { //if it is the last packet for this report change the message type to uart_resp_bt_neigh_rep_end
		packet.type = uart_resp_bt_neigh_rep_end;
		n = 0;
		payload_free_from = 0;
	}

	if (n == 0) {	//this is executed after the transmission of uart_resp_bt_neigh_rep_end
		reset_network(); //TODO: a specific function for resetting ONLY reported nodes should be used
	}

    PRINTF("Returning n=%u\n",n);

    uart_util_send_pkt(&packet);
	return (uint8_t)n;
}

void cancel_ongoing_report(void) {
    sequential_procedure_stop_this(&ble_report);
}

void send_pong(uart_pkt_t* p_packet) {
    PRINTF("Sending pong packet\n");
	if (p_packet->payload.data_len) {
		uint8_t pong_payload[p_packet->payload.data_len];
		memcpy(pong_payload, p_packet->payload.p_data, p_packet->payload.data_len);

		uart_pkt_t pong_packet;
		pong_packet.payload.p_data = pong_payload;
		pong_packet.payload.data_len = p_packet->payload.data_len;
		pong_packet.type = uart_pong;

		uart_util_send_pkt(&pong_packet);
	} else {
		uart_pkt_t pong_packet;
		pong_packet.payload.p_data = NULL;
		pong_packet.payload.data_len = p_packet->payload.data_len;
		pong_packet.type = uart_pong;

		uart_util_send_pkt(&pong_packet);
	}
}

#define PING_PACKET_SIZE		10
//example of use of uart_util_send. This function is called with a timer and send a packet to the UART
uint8_t send_ping(void) {
    PRINTF("Sending ping packet\n");
	/*  CREATE DUMMY UINT8 ARRAY   */
#if PING_PACKET_SIZE != 0
	uint8_t payload[PING_PACKET_SIZE];
	for (uint16_t i = 0; i < PING_PACKET_SIZE; i++) {
		payload[i] = PING_PACKET_SIZE - i;
	}
	/*  CREATE A PACKET VARIABLE */
	uart_pkt_t packet;
	packet.payload.p_data = payload;
	packet.payload.data_len = PING_PACKET_SIZE;
	packet.type = uart_ping;
#else
	uart_pkt_t packet;
	packet.payload.p_data = NULL;
	packet.payload.data_len = PING_PACKET_SIZE;
	packet.type = uart_ping;
#endif
	/*  SEND THE PACKET  */
	uart_util_send_pkt(&packet);

    return 0;
}

uint8_t send_ready(void) {
    PRINTF("Sending ready packet\n");
	char version_string[] = STRINGIFY(VERSION_STRING);

	uart_pkt_t pong_packet;
	pong_packet.payload.p_data = (uint8_t*)version_string;
	pong_packet.payload.data_len = strlen(version_string);
	pong_packet.type = uart_evt_ready;

	uart_util_send_pkt(&pong_packet);

	return 0;
}
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
int main(void) {
    log_init();
	initialize_leds();
	timer_init();
	initialize_uart();
	buttons_init();
	ble_stack_init();
	gap_params_init();

	reset_network();
	client_init();
	services_init();
    //gatt_mtu_set(m_test_params.att_mtu);
    //data_len_ext_set(m_test_params.data_len_ext_enabled);
    //conn_evt_len_ext_set(m_test_params.conn_evt_len_ext_enabled);
    //preferred_phy_set(&m_test_params.phys);
	advertising_data_set();

//#ifdef DNRF52840_XXAA
//    (void) sd_ble_gap_tx_power_set(9);
//#else
//    (void) sd_ble_gap_tx_power_set(4);
//#endif

	preferred_phy_set(&m_test_params.phys);

	buttons_enable();

	application_timers_start();

    PRINTF("Running!\n");

#if defined(ENABLE_TOF) && ENABLE_TOF==1
    tof_init();
    ifs_offset_ticks = calculate_ifs_offset(m_test_params.phys);
    if(m_ifs_tof_active){
        ble_tof_start();
    }
#endif

    nrf_delay_ms(1000); //delay a bit to allow all the hardware to be ready (not strictly necessary)
	start_procedure(&ready);

	while (1) {
        if (NRF_LOG_PROCESS() == false) // Process logs
        {
            wait_for_event();
        }
	}
}

/**
 * @}
 */

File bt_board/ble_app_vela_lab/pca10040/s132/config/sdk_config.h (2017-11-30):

/**
 * Copyright (c) 2017 - 2017, Nordic Semiconductor ASA
 * 
 * All rights reserved.
 * 
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
 * 3. Neither the name of Nordic Semiconductor ASA nor the names of its
 *    contributors may be used to endorse or promote products derived from this
 *    software without specific prior written permission.
 * 
 * 4. This software, with or without modification, must only be used with a
 *    Nordic Semiconductor ASA integrated circuit.
 * 
 * 5. Any software provided in binary form under this license must not be reverse
 *    engineered, decompiled, modified and/or disassembled.
 * 
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
 */



#ifndef SDK_CONFIG_H
#define SDK_CONFIG_H
// <<< Use Configuration Wizard in Context Menu >>>\n
#ifdef USE_APP_CONFIG
#include "app_config.h"
#endif
// <h> Application 

//==========================================================
// <o> ADV_INTERVAL - Advertising interval (in units of 0.625 ms) 
#ifndef ADV_INTERVAL
#define ADV_INTERVAL 640
#endif

// <s> DEVICE_NAME - Name of device. Will be included in the advertising data.
#ifndef DEVICE_NAME
#define DEVICE_NAME "Nordic_ATT_MTU"
#endif

// <o> SCAN_INTERVAL - Scanning interval, determines scan interval in units of 0.625 millisecond. 
#ifndef SCAN_INTERVAL
#define SCAN_INTERVAL 8
#endif

// <o> SCAN_WINDOW - Scanning window, determines scan window in units of 0.625 millisecond. 
#ifndef SCAN_WINDOW
#define SCAN_WINDOW 8
#endif

// </h> 
//==========================================================

// <h> nRF_BLE 

//==========================================================
// <q> BLE_ADVERTISING_ENABLED  - ble_advertising - Advertising module
 

#ifndef BLE_ADVERTISING_ENABLED
#define BLE_ADVERTISING_ENABLED 0
#endif

// <q> BLE_DB_DISCOVERY_ENABLED  - ble_db_discovery - Database discovery module
 

#ifndef BLE_DB_DISCOVERY_ENABLED
#define BLE_DB_DISCOVERY_ENABLED 1
#endif

// <q> BLE_DTM_ENABLED  - ble_dtm - Module for testing RF/PHY using DTM commands
 

#ifndef BLE_DTM_ENABLED
#define BLE_DTM_ENABLED 0
#endif

// <q> BLE_RACP_ENABLED  - ble_racp - Record Access Control Point library
 

#ifndef BLE_RACP_ENABLED
#define BLE_RACP_ENABLED 0
#endif

// <q> NRF_BLE_GATT_ENABLED  - nrf_ble_gatt - GATT module
 

#ifndef NRF_BLE_GATT_ENABLED
#define NRF_BLE_GATT_ENABLED 1
#endif

// <q> NRF_BLE_QWR_ENABLED  - nrf_ble_qwr - Queued writes support module (prepare/execute write)
 

#ifndef NRF_BLE_QWR_ENABLED
#define NRF_BLE_QWR_ENABLED 0
#endif

// <e> PEER_MANAGER_ENABLED - peer_manager - Peer Manager
//==========================================================
#ifndef PEER_MANAGER_ENABLED
#define PEER_MANAGER_ENABLED 0
#endif
// <o> PM_MAX_REGISTRANTS  
// <i> Number of event handlers that can be registered.

#ifndef PM_MAX_REGISTRANTS
#define PM_MAX_REGISTRANTS 3
#endif

// <o> PM_FLASH_BUFFERS  
// <i> Number of internal buffers for flash operations.
// <i> Decrease this value to lower RAM usage.

#ifndef PM_FLASH_BUFFERS
#define PM_FLASH_BUFFERS 8
#endif

// </e>

// </h> 
//==========================================================

// <h> nRF_BLE_Services 

//==========================================================
// <q> BLE_ANCS_C_ENABLED  - ble_ancs_c - Apple Notification Service Client
 

#ifndef BLE_ANCS_C_ENABLED
#define BLE_ANCS_C_ENABLED 0
#endif

// <q> BLE_ANS_C_ENABLED  - ble_ans_c - Alert Notification Service Client
 

#ifndef BLE_ANS_C_ENABLED
#define BLE_ANS_C_ENABLED 0
#endif

// <q> BLE_BAS_C_ENABLED  - ble_bas_c - Battery Service Client
 

#ifndef BLE_BAS_C_ENABLED
#define BLE_BAS_C_ENABLED 0
#endif

// <q> BLE_BAS_ENABLED  - ble_bas - Battery Service
 

#ifndef BLE_BAS_ENABLED
#define BLE_BAS_ENABLED 0
#endif

// <q> BLE_CSCS_ENABLED  - ble_cscs - Cycling Speed and Cadence Service
 

#ifndef BLE_CSCS_ENABLED
#define BLE_CSCS_ENABLED 0
#endif

// <q> BLE_CTS_C_ENABLED  - ble_cts_c - Current Time Service Client
 

#ifndef BLE_CTS_C_ENABLED
#define BLE_CTS_C_ENABLED 0
#endif

// <q> BLE_DIS_ENABLED  - ble_dis - Device Information Service
 

#ifndef BLE_DIS_ENABLED
#define BLE_DIS_ENABLED 0
#endif

// <q> BLE_GLS_ENABLED  - ble_gls - Glucose Service
 

#ifndef BLE_GLS_ENABLED
#define BLE_GLS_ENABLED 0
#endif

// <q> BLE_HIDS_ENABLED  - ble_hids - Human Interface Device Service
 

#ifndef BLE_HIDS_ENABLED
#define BLE_HIDS_ENABLED 0
#endif

// <q> BLE_HRS_C_ENABLED  - ble_hrs_c - Heart Rate Service Client
 

#ifndef BLE_HRS_C_ENABLED
#define BLE_HRS_C_ENABLED 0
#endif

// <q> BLE_HRS_ENABLED  - ble_hrs - Heart Rate Service
 

#ifndef BLE_HRS_ENABLED
#define BLE_HRS_ENABLED 0
#endif

// <q> BLE_HTS_ENABLED  - ble_hts - Health Thermometer Service
 

#ifndef BLE_HTS_ENABLED
#define BLE_HTS_ENABLED 0
#endif

// <q> BLE_IAS_C_ENABLED  - ble_ias_c - Immediate Alert Service Client
 

#ifndef BLE_IAS_C_ENABLED
#define BLE_IAS_C_ENABLED 0
#endif

// <q> BLE_IAS_ENABLED  - ble_ias - Immediate Alert Service
 

#ifndef BLE_IAS_ENABLED
#define BLE_IAS_ENABLED 0
#endif

// <q> BLE_LBS_C_ENABLED  - ble_lbs_c - Nordic LED Button Service Client
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

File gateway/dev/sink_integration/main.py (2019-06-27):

import serial
import time
import datetime
import logging
from recordtype import recordtype
from enum import IntEnum, unique
from datetime import timedelta
import _thread
import readchar
import os
import sys
import threading
from collections import deque
import shutil
import binascii

START_CHAR = '02'
#START_BUF = '2a2a2a'  # this is not really a buffer
BAUD_RATE = 1000000 #921600 #1000000
SERIAL_PORT = "/dev/ttyS0" #"/dev/ttyACM0" #"/dev/ttyS0"

if len(sys.argv)>1:
	SERIAL_PORT=sys.argv[1]

if len(sys.argv)>2:
	BAUD_RATE=int(sys.argv[2])


logfolderpath = os.path.dirname(os.path.realpath(__file__))+'/log/'
if not os.path.exists(logfolderpath):
    try:
        os.mkdir(logfolderpath)
        net.addPrint("Log directory not found.")
        net.addPrint("%s Created " % logfolderpath)
    except Exception as e:
        net.addPrint("Can't get the access to the log folder %s." % logfolderpath)
        net.addPrint("Exception: %s" % str(e))


endchar = 0x0a
SER_END_CHAR = endchar.to_bytes(1, byteorder='big', signed=False)

SINGLE_NODE_REPORT_SIZE = 9      #must be the same as in common/inc/contraints.h
MAX_REPORTS_PER_PACKET = 22 #must be the same as in common/inc/contraints.h
MAX_PACKET_PAYLOAD = SINGLE_NODE_REPORT_SIZE*MAX_REPORTS_PER_PACKET

MAX_BEACONS = 100

MAX_ONGOING_SEQUENCES = 10

MAX_TRICKLE_C_VALUE = 256

ser = serial.Serial()
ser.port = SERIAL_PORT
ser.baudrate = BAUD_RATE
ser.timeout = 100

MessageSequence = recordtype("MessageSequence", "timestamp,nodeid,lastPktnum,sequenceSize,datacounter,"
                                                "datalist,latestTime")
messageSequenceList = []
ContactData = recordtype("ContactData", "nodeid lastRSSI maxRSSI pktCounter")

firstMessageInSeq = False

NodeDropInfo = recordtype("NodeDropInfo", "nodeid, lastpkt")
nodeDropInfoList = []

ActiveNodes = []

deliverCounter = 0
dropCounter = 0
headerDropCounter = 0
defragmentationCounter = 0

# Timeout variables
previousTimeTimeout = 0
currentTime = 0
timeoutInterval = 300
timeoutTime = 60

previousTimePing = 0
pingInterval = 115

btPreviousTime = 0
btToggleInterval = 1800
btToggleBool = True

NODE_TIMEOUT_S = 60*10
NETWORK_PERIODIC_CHECK_INTERVAL = 2
CLEAR_CONSOLE = True

# Loggers
printVerbosity = 10

LOG_LEVEL = logging.DEBUG

formatter = logging.Formatter('%(asctime)s %(levelname)s %(message)s', datefmt='%Y/%m/%d %H:%M:%S')
timestr = time.strftime("%Y%m%d-%H%M%S")

nameConsoleLog = "consoleLogger"
filenameConsoleLog = timestr + "-console.log"
fullpathConsoleLog = logfolderpath+filenameConsoleLog
consolloghandler = logging.FileHandler(fullpathConsoleLog)
consolloghandler.setFormatter(formatter)
consoleLogger = logging.getLogger(nameConsoleLog)
consoleLogger.setLevel(LOG_LEVEL)
consoleLogger.addHandler(consolloghandler)

nameUARTLog = "UARTLogger"
filenameUARTLog = timestr + "-UART.log"
fullpathUARTLog = logfolderpath+filenameUARTLog
handler = logging.FileHandler(fullpathUARTLog)
handler.setFormatter(formatter)
UARTLogger = logging.getLogger(nameUARTLog)
UARTLogger.setLevel(LOG_LEVEL)
UARTLogger.addHandler(handler)

nameContactLog = "contactLogger"
filenameContactLog = timestr + "-contact.log"
fullpathContactLog = logfolderpath+filenameContactLog
contactlog_handler = logging.FileHandler(fullpathContactLog)
contact_formatter = logging.Formatter('%(message)s')
contactlog_handler.setFormatter(contact_formatter)
contactLogger = logging.getLogger(nameContactLog)
contactLogger.setLevel(LOG_LEVEL)
contactLogger.addHandler(contactlog_handler)

nameErrorLog = "errorLogger"
filenameErrorLog = timestr + "-errorLogger.log"
fullpathErrorLog = logfolderpath+filenameErrorLog
errorlog_handler = logging.FileHandler(fullpathErrorLog)
errorlog_formatter= logging.Formatter('%(message)s')
errorlog_handler.setFormatter(errorlog_formatter)
errorLogger = logging.getLogger(nameErrorLog)
errorLogger.setLevel(LOG_LEVEL)
errorLogger.addHandler(errorlog_handler)
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

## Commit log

2017-11-17 Various improvements on UART communication and BLE scanning
    - uart ack change to application ack
    - add uart_resp_bt_neigh_rep_end type to indicate the report is over
    - ack error now have one argument with some data regarding the ack
    - added contraints.h which contains various constants used by the projects
    - added filter for BLE beacons (filters CLIMBC nodes and eddystone with the correct namespace)
    - Makefile clean
    - bug fix
    [constraints.h, main.c]
2017-11-17 Add support for CLIMB beacon and Eddystone beacon
    - now a filter discard all adv packets which are not CLIMBC devices or Eddystone with a predefined namespace
    - the report now uses ID and no more bd (mac) address
    - the seen_since part of report is now in millisecond and no more in ticks
    - some part of code has been splitted and put into functions
    - changing some define names
    - minor bugs and code clean
    [constraints.h, main.c]
2017-11-17 Changing report
    - now the "seen_since" field of the report is in second (16 bits), no more in millis
    - the report includes also the beacon_msg_count
2017-11-21 Blink led on nrf52dk and code version on both boards
    - an uart ack error is signaled with a blink of led4 in the nrf52dk
    - the code version string is added as payload of the uart_ready messagges. The build number is automatically increased by the build_script.sh. Thi
    [main.c]
2017-11-21 Changing the logic of the contiki app
    Now as the BLE board is disconnected the contiki app periodically sends uart_ping packets
2017-11-21 Use struct in place of ptr+size
    moving data_t into uart_util.h so that now it is shared
2017-11-21 integration code --- currently not working
2017-11-21 Moving the uart flow control enable outside contiki sources
    By default contiki do not enable flow control on the uart but we need it.
    Now the enable is done in uart_util.c when the initialization routine is called.
2017-11-22 adding new files for unit testing the uart
2017-11-22 bringing makefile in line with new unit test structure for uart
2017-11-22 Changing structure for improved unit test capabilities and compatibility with uart
2017-11-22 Remove test-uart.c
    the file content has been moved to vela_uart.c
2017-11-22 working version of the dummy uart with the real RPL sender and receiver.
2017-11-22 fixing repository to add missing files for test sender
    [vela_uart.c]
2017-11-22 adding led toggle when starting to send
2017-11-22 Bug fix
    There was a logic error when the report was splitted in multiple uart packets.
    [main.c]
2017-11-22 Bug fix for reports on splitted uart packets
    [vela_uart.c]
2017-11-22 Setting the uart ack timeout to 0.5s to both boards of the mobile node
2017-11-23 Change the report structure and network reset logic
    [main.c]
2017-11-23 fixing debug to off
    [vela_sender.c]
2017-11-28 decreasing uart baudrate
    working at 1M give errors, then switch to 115200
2017-11-28 BM: printchar decoding
2017-11-29 BM: corrected typo in /gateway/dev/serial_test/
    [serial_test_printchar.py, serial_test_printhex.py]
2017-11-29 Apply some power optimization on nordic
    - The leds are activated with a low duty cycle
    - Adding/changing leds meaning
    - The UART is set in IRQ mode and no more in DMA mode
    - Removing 'static' from functions
2017-11-30 UART to 921600 baud between nordic and TI
    The baudrate were reduced on a previous commit because it was not reliable, but it came out that the problem was related to the buffsize (with buffsize=256 a variable overflowed) in contiki and not in the baudrate.
    So switch the baudrate to the standard 921600 and decrease the buffsize to 128
    [vela_uart.c]
2017-12-01 Adding nordic watchdog on contiki
    If the nordic doesn't send packets the TI reset it!
    For now the change is not active and it needs to be tested
    [vela_uart.c]
2017-12-01 Every uart @ 1Mbaud
2017-12-04 uart_util optimization/fix
    This fix lightly reinforce the uart communication
2017-12-05 uart tx_error led fix
    the tx_error led weren't reset properly
    [main.c]
2017-12-05 Add a led toggle
    Now the green led is toggled every time a packet is received from the mesh network
2017-12-06 remove printf during
2017-12-11 Enabling the watchdog for the nordic board.
    If the nordic doesn't send any packet, after a while the TI enters in a while(1) loop and then the contiki watchdog fires a reset
    [vela_uart.c]
2017-12-14 BM: SensorTag sink @ 3MBaud
2017-12-15 Enable uart RX on the sink
    The UART must remain out of low power otherwise there are errors in the communication (even if only the TX is used!)
    [sink_receiver.c]
2018-08-31 PCB made by Ramez Ghobrial during his internship at FBK
    Now a real PCB exists for interconnecting the two boards.
    The PCB provides the eletrical interface and does also power management given the solar panel charger and the fuel gauge.
    This PCB haven't been tested and it may have problems when both solar harvester and USB charger are active. If this situation never happen the PCB should work.
    [BOM.xlsx, BOM_v3.0.xlsx, EHcircuit_v1.0.brd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]
2018-10-02 New design added
    [BOM.xlsx, BOM_v3.0.xlsx, EHcircuit_v1.0.brd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]
2018-10-04 First version new PCB added
    [SolarPowerBoard.brd, SolarPowerBoard.sch]
2018-10-05 Small fixes pcb design
2018-10-05 First check. Few things to modify:
    - rearrange kelvin connections on sensing resistor (and routing around the fuel gauge)
    - add LED on CBUS1 and CBUS2 of the FTDI chip (see powerDevPack project), or remove the CBUS1 and CBUS2 connections
    - edit the JST connector footprint and increase holes size (see J5 footprint as reference)
    [SolarPowerBoard.brd, SolarPowerBoard.sch]
2018-10-08 Fixed library link. Several small problems fixed.
    [SolarPowerBoard.brd, SolarPowerBoard.sch]
2018-10-08 Changed drill holes in JST connectors
2018-10-08 Added Nordic TX pin pull up resistor
    [SolarPowerBoard.brd, SolarPowerBoard.sch]
2018-10-08 Changed inductor footprint
    [SolarPowerBoard.brd, SolarPowerBoard.sch]
2018-10-08 Changed sense resistor
    [SolarPowerBoard.brd, SolarPowerBoard.sch]
2018-10-09 Added 0ohm resistor between UART AND port and RX pin. Removed library autosave files.
    [SolarPowerBoard.brd, SolarPowerBoard.sch]
2018-11-12 commiting the PCB printed ad eurocircuit (very first version)
    [SolarPowerBoard.brd, SolarPowerBoard.sch]
2018-11-12 supported commands through uart inteface doc
    [uart_cmd_def_velaLab.xlsx]
2018-11-15 fix bug in pong message
    [main.c]
2018-11-26 Add UART interupt priority on VELA NODES
2018-11-26 Adding MAX17260 fuel gauge sensor in the application files
    - adds a project with only i2c initialization and fuel gauge example
    - add the CodeComposerStudio project for the i2c init
    - change the integrate_sender_uart project to use the fuel gauge if the target is launchpad_vela
2018-11-26 add workaround the TX/RX swap in the solar panel board
2018-11-27 Small change in the uart_util.c
    There was a risk of entering infinite loop if the status = error
2018-11-27 Added Bram's code used for the first solar panel test
    [network_commands.ods]
2018-11-29 PCB project update
    - arduino header fix
    - text fix
    - library refactor (now all the capacitor use the same component as well as resistors)
    [SolarPowerBoard.brd, SolarPowerBoard.sch]
2018-12-04 fix for basic sender test that was rebooting
    this version targets (and works on) cc1350 launchpad, cc2560 not yet tested
    [project-conf.h, vela_sender.c, vela_uart.c]
2018-12-05 Adding MAX17260 temperature reading
2018-12-06 Changed variables to static in uart code
2018-12-07 add uart_util_is_waiting_ack to uart_util
2018-12-07 cleaning of vela_uart.c and fix some bugs, now the procedure stuff seems to be stable
    [vela_uart.c]
2018-12-12 Sequential procedures module
    - now to communicate over the uart both boards use sequential_procedure module
    - added log over rtt on the nordic
    - added verbosity on both boards
2018-12-12 Sequential procedures module
    - some functions have been changed to 'static'
    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
2018-12-12 Stable version?
    [network_commands.ods]
2018-12-13 trickle fix (multihop was not working)
    [vela_sender.c]
2018-12-13 Partial fix of race condition on report procedure and ack
    [main.c]
2018-12-19 printf change (now they use macros which are set to NOP when DEBUG=0)
    Also IMIN IMAX macro has chenged to avoid redefinition warning
    [main.c, project-conf.h, sink_receiver.c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]
2018-12-19 Adding delay to ack.
    It seemed that the TI sent the uart ack to fast and the nordic wasn't able to handle it
2018-12-19 Fix on trickle message length being transmitted.
    [main.py, sink_receiver.c, vela_sender.c]
2018-12-21 Hardware: reset out pin now can be routed to DIO22 instead of DIO1 which is reserved for the rf switch on cc1350 launchpads
    [SolarPowerBoard.brd, SolarPowerBoard.sch]
2019-01-02 adding the documentation of the uart packet structure used by uart_util module
    [uart_packet_struct.xlsx]
2019-01-02 gateway to sink communication is now coded
    to avoid false '\n' and '\00' the communication from the gateway to the sink is coded using ascii representation of hexadecimal data (i.e. only '0' to '9' and 'A' to 'F' chars are transmitted over the uart)
    This applies only to gateway to sink communication, sink to gateway remains unaffected
    [main.py, sink_receiver.c]
2019-01-04 Adding commands from the gateway: - battery report interval - nordic reset Deprecating commands: - turn on bt low - turn on bt high (both can be replicated with turn on bt with params)
    [main.py]
2019-01-04 minor PRINTF change
2019-01-04 Fix memory copy in place of pointer copy
    [vela_sender.c]
2019-01-04 fix on report timeout.
    Now it properly stores the last value and use it till a new timeout is received from the mesh network
    [vela_uart.c]
2019-01-04 Adding commands to the network.
    Now the nodes properly handles:
    - reset nordic command
    - battery report interval change and turn off
    - keepalive turn off
    [vela_node.c, vela_sender.c, vela_uart.c]
2019-01-07 Fix for non fuel gauge equipped boards
    [vela_node.c]
2019-01-07 Fixed contact data plotter
    [contact_plotter.py]
2019-01-08 Fixed contact plotting code
    [contact_plotter.py]
2019-01-14 Updated network_commands document
    [network_commands.xlsx]
2019-01-14 Small addition to network_commands and deleted old file
    [network_commands.ods, network_commands.xlsx]
2019-01-28 change nrf reset to the new pin (gpio22 of the cc)
    [vela_uart.c]
2019-01-28 minor bug (if nordic was reset and the report was enabled a reset was triggered)
    [vela_uart.c]
2019-01-29 bug fix on nordic
    memory was not properly reset
    [main.c]
2019-01-29 adding trickle counter in keepalive packets and send battery voltage in place of soc
2019-01-29 remove self reset with NORDIC_WATCHDOG_ENABLED
    [vela_uart.c]
2019-01-31 rename pin so that it compiles easilly also for the sensortag platform
2019-01-31 redesign of the terminal interface
    [main.py]
2019-02-18 Add print in case of error (TBC)
    [main.py]
2019-02-18 Better handling of unknwown uart part
2019-02-19 sink to gateway communication review
    - now for the sinkToGateway communication we use hex formatted string, however the structure of uart frames isn't unified in the two directions
    - the uart is read line by line (not char by char)
    - added an error logger to log unknown uart frames (this is mainly for debug)
    [main.py, sink_receiver.c]
2019-02-19 a random delay is added to the handling of all the trickle packets. This to avoid collisions
    [vela_sender.c]
2019-02-21 Some graphical fix and improvement and general log revision
    [main.py]
2019-02-22 python script: add resetcounter command + bug fix + graphical improvements
    [main.py]
2019-03-13 better handling of ack errors
    [main.c]
2019-03-13 adding a kind of lock to avoid command handling during the transmission of the BLE report from the nordic to the TI, also a better handling of uart_util_ack_error
    [vela_uart.c]
2019-06-27 Various fixes (static variables, application level watchdog for network offline, etc)
    [main.c, main.py, project-conf.h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]
2019-07-15 Adding code to send chunks of images from sink to nodes. This is an intermediate step and has been tested with Cooja. Currently, the checked-in version has several TODO entries that need to be addres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
